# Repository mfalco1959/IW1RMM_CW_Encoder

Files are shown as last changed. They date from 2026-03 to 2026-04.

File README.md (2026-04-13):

# IW1RMM CW Encoder
Live demo:  
https://mfalco1959.github.io/IW1RMM_CW_Encoder/
**Firmware v7.1.5 — IW1RMM (Mauri)**

Morse code keyer WinKey WK3-compliant per ESP32-2432S028R (CYD), con display ILI9341 320×240 touchscreen.
Basato sul firmware originale di VK2IDL, esteso e adattato per il CYD.

---

## Hardware

### Schema elettrico

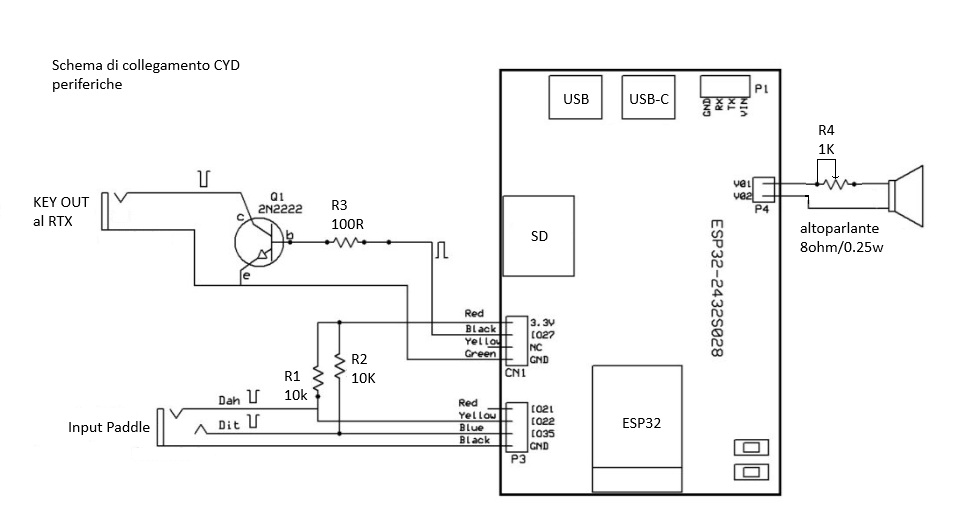
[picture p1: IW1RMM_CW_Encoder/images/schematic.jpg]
Schema elettrico del CW Keyer


### Collegamento paddle e tasto verticale

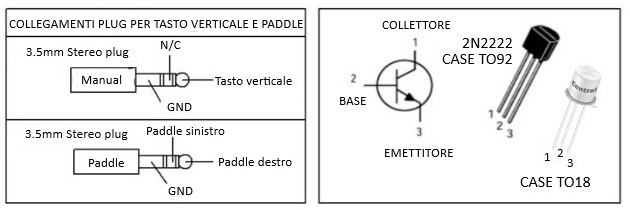
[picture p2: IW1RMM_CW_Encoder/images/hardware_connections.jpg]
Collegamento plug tasto verticale e paddle — transistor 2N2222 TO-92 e TO-18


### Vista interna dei collegamenti

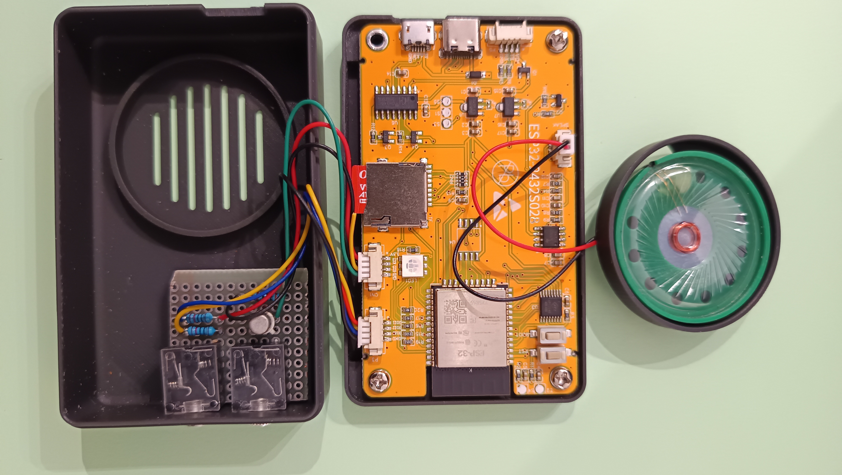
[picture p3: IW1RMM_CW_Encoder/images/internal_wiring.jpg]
Vista interna dei collegamenti


### Vista d'insieme

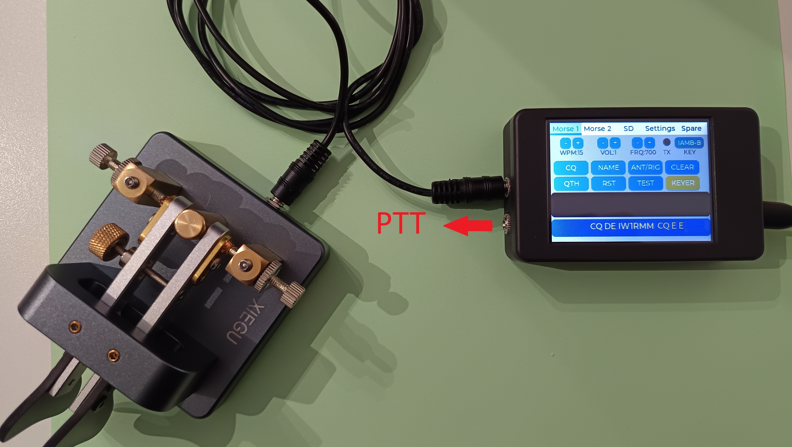
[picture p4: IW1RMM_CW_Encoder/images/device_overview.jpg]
Il CYD nel case con il paddle collegato


---

## Funzionalità

- WinKey WK3 via USB Serial (1200 baud)
- K3NG ASCII command set via Serial e BLE Nordic UART
- LVGL touchscreen UI (5 tab)
- Modalità keyer: Iambic A/B, Bug, Auto, Ultimatic
- SD card playback con logging CSV
- QRSS / HSCW / Beacon / Contest
- Calibrazione touch interattiva a 4 punti
- Orologio con offset GMT, supporto DS3231 RTC
- Farnsworth, Prosign, DAH ratio, Spacing weight
- Memorie K3NG A–Z (NVS)
- Messaggi preimpostati (6 slot, NVS)

---

## Interfaccia — Screenshots

### Tab Morse 1

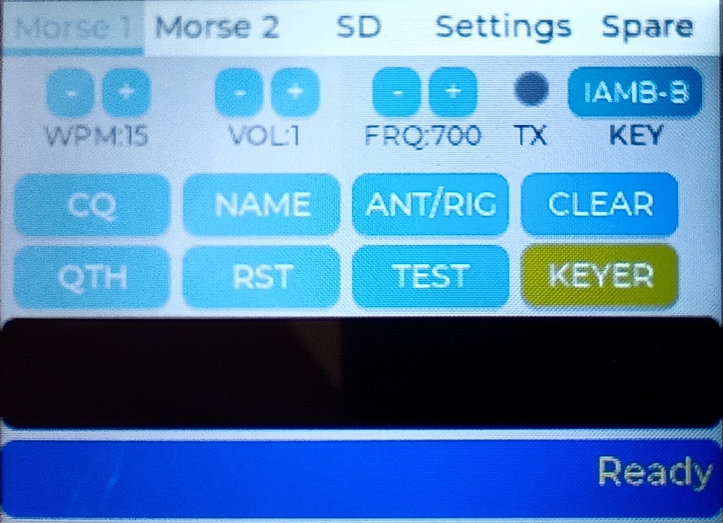
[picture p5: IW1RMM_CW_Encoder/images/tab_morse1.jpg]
Schermata Tab Morse 1


### Keyboard — long press

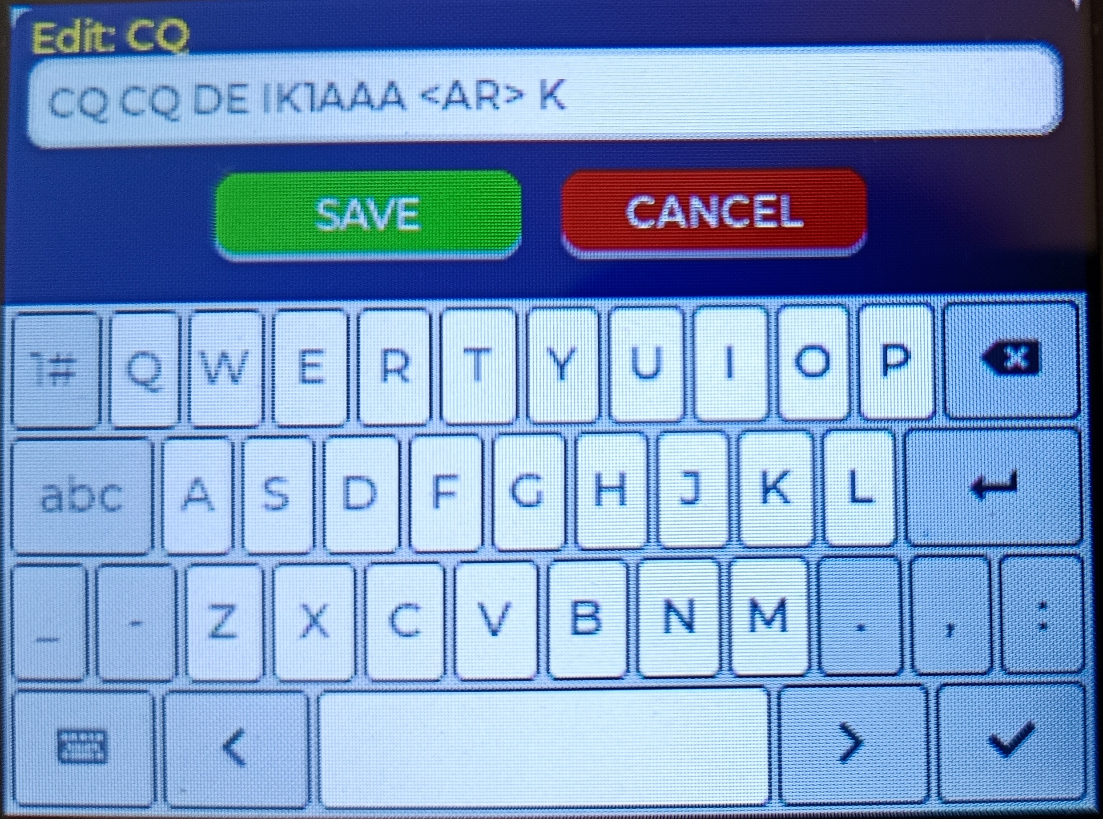
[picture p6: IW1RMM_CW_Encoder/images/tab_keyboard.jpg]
Schermata Keyboard — long press sui tasti CQ, NAME ecc.


### Tab Morse 2

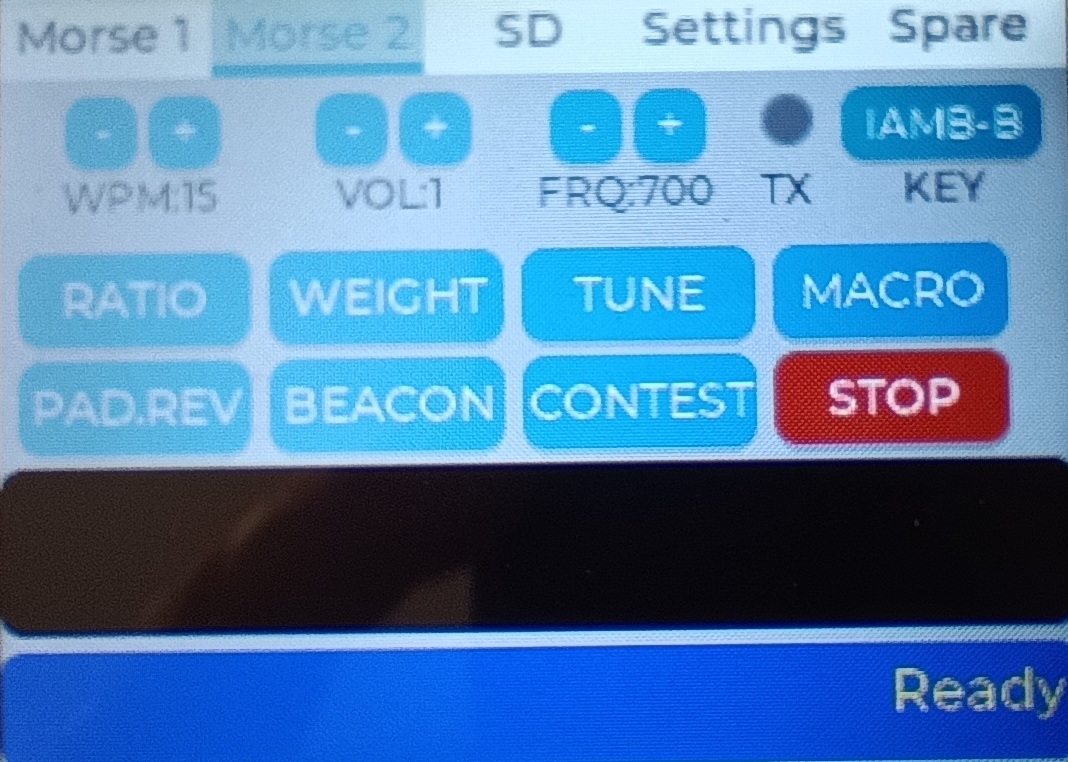
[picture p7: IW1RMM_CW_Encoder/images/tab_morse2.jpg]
Schermata Tab Morse 2


### Tab SD

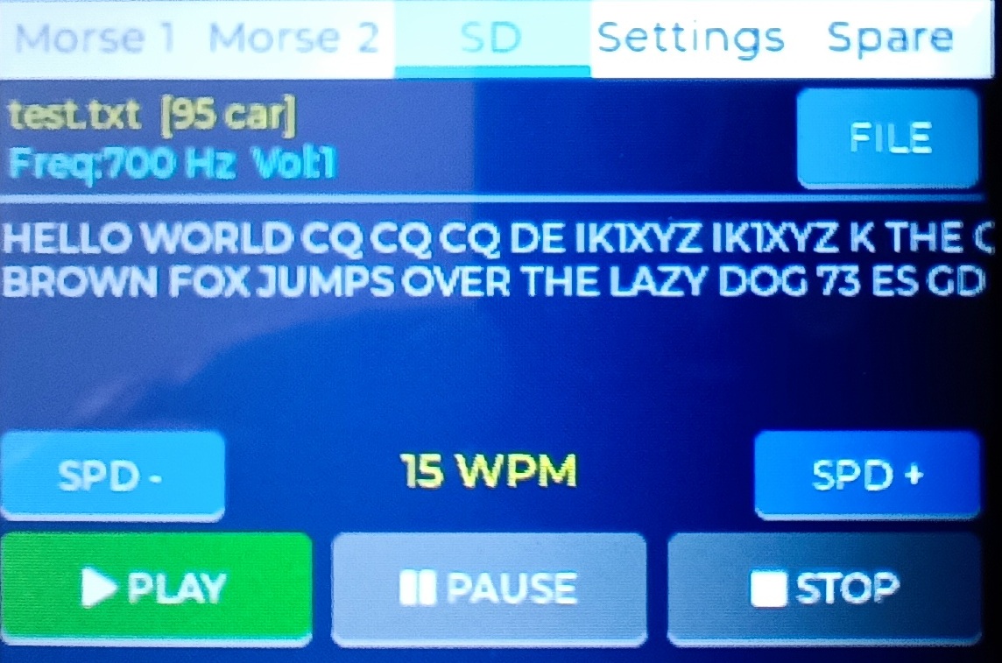
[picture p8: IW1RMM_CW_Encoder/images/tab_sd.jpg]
Schermata Tab SD


### Tab Settings — stato di default

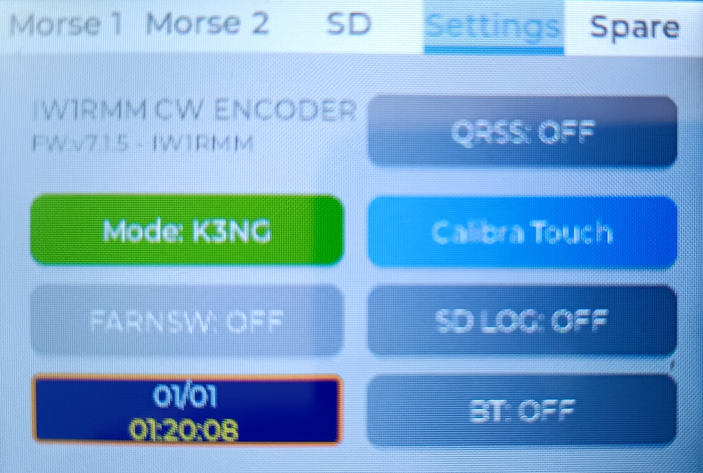
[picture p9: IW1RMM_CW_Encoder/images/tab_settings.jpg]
Schermata Tab Settings — stato di default


### Tab Settings — con i tasti attivi

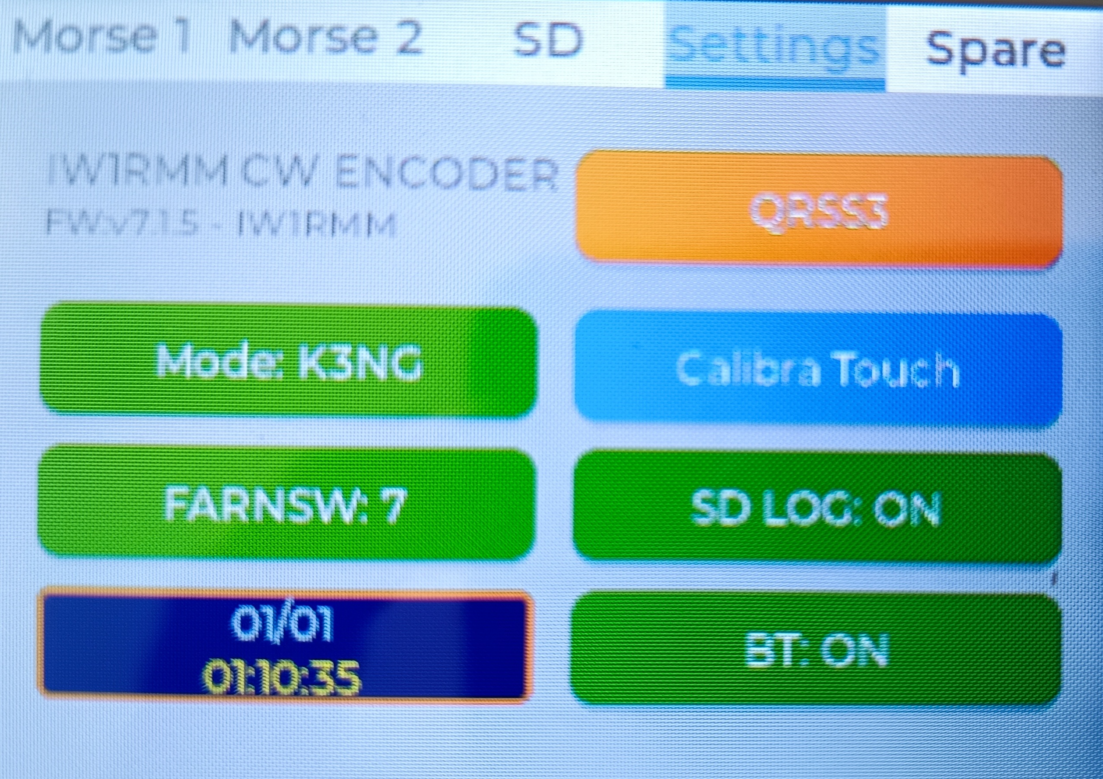
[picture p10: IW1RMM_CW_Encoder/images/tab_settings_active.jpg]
Schermata Tab Settings — con i tasti attivi


---

## BLE

Il firmware espone un servizio Nordic UART (NUS) con nome **VK2IDL_Morse**.  
Supporta lo stesso set di comandi K3NG disponibile via Serial.

### Comandi K3NG via BLE — screenshot smartphone

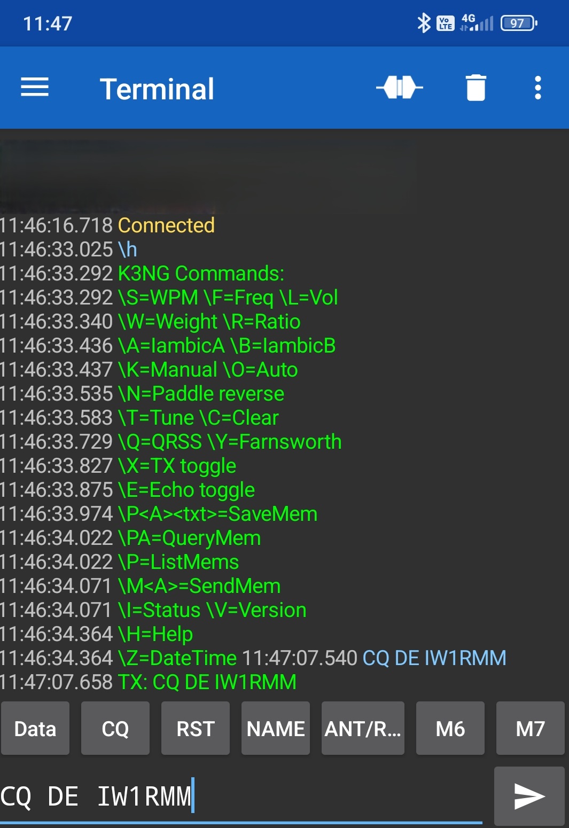
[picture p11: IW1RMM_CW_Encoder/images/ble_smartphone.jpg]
Screenshot smartphone — comandi K3NG via BLE


---

## Pinout ESP32-2432S028R (CYD)

| GPIO | Funzione | Note |
|---|---|---|
| 27 | KEY / PTT output | Uscita keyer |
| 26 | Sidetone DAC | Audio 300–1200 Hz |
| 22 | DIT input | Paddle |
| 21 | DAH input | Paddle |
| 5 | SD_CS | SPI SD card |
| 23 | SD_MOSI | SPI SD card |
| 19 | SD_MISO | SPI SD card |
| 18 | SD_SCK | SPI SD card |
| 2 | TFT_RS | Display ILI9341 |
| 15 | TFT_CS | Display ILI9341 |
| 4 | XPT2046 CS | Touch |
| 36 | XPT2046 IRQ | Touch interrupt |

---

## Dipendenze (librerie Arduino)

| Libreria | Versione | Autore |
|---|---|---|
| lvgl | **8.4.0** | LVGL |
| TFT_eSPI | **2.5.43** | Bodmer |
| XPT2046_Touchscreen | **1.4** | Paul Stoffregen |
| DacESP32 | **2.1.2** | Thomas Jentzsch |
| Preferences (NVS) | built-in | Espressif |
| BLE (BLEDevice/BLEServer/BLEUtils/BLE2902) | built-in | Espressif |

> ⚠️ Testato con ESP32 Arduino Core **3.x**. Le librerie BLE e DacESP32 richiedono Core 3.x — non usare la versione 2.x.

---

## Installazione

1. Clona il repository
```bash
git clone https://github.com/TUO_USER/IW1RMM_CW_Encoder.git
```
2. Copia `include/lv_conf.h` nella cartella dello sketch (stessa directory di `IW1RMM_CW_Encoder.ino`)
3. Configura `User_Setup.h` di TFT_eSPI (vedi `docs/User_Setup_example.h`)
4. Compila con Arduino IDE — board: **ESP32 Dev Module**  
   In **Tools**, imposta:
   - Flash Mode: **DIO**
   - Flash Frequency: **40MHz**
   - Partition Scheme: **Huge APP (3MB No OTA/1MB SPIFFS)**
   - Upload Speed: **115200**
5. Upload via Arduino IDE — il firmware è di grandi dimensioni, **l'upload richiederà alcuni minuti**.

> ⚠️ **DIO + 40MHz sono obbligatori.** Le schede CYD usano spesso il chip flash ZBIT ZB25VQ32, sensibile a impostazioni QIO o 80MHz — l'uso di QIO o 80MHz può causare errori di upload o boot loop.

> 💡 **Velocità di upload:** 115200 baud è il valore sicuro e raccomandato. Se si prevede di fare pochi upload è possibile provare a incrementare la velocità (es. 460800 o 921600) per ridurre i tempi, ma la stabilità dipende dal cavo USB e dal driver del PC.

---

## Comandi K3NG principali

| Comando | Funzione |
|---|---|
| `\Snn` | Imposta velocità (WPM) |
| `\Fnnnn` | Imposta frequenza sidetone (Hz) |
| `\Ln` | Imposta livello volume (0–4) |
| `\R nnn` | DAH ratio × 100 (es. \R300 = 3.0) |
| `\W nnn` | Spacing weight × 100 (es. \W100 = 1.0) |
| `\Y nn` | Farnsworth WPM (0 = disabilita) |
| `\Q n` | QRSS (0/3/6/10/30 secondi per dit) |
| `\T` | TUNE — portante continua |
| `\J` | Reset calibrazione touch |
| `\Z DDMMAAAAHHmmSS` | Imposta orologio |
| `\G ±n` | Offset GMT |
| `\PA testo` | Salva memoria K3NG (A–Z) |
| `\MA` | Invia memoria K3NG A |
| `\P` | Lista tutte le memorie |
| `\?` | Help completo |

---

## Versione

| Versione | Data | Note |
|---|---|---|
| v7.1.4 | 2026-03 | Touch calibration, prosign, DS3231, K3NG esteso |

---

## Crediti

- Firmware originale: **VK2IDL**
- Modifiche, estensioni e adattamento CYD: **IW1RMM (Mauri)**, 2025–2026

---

## Licenza

GPL v3 — vedi file `LICENSE`

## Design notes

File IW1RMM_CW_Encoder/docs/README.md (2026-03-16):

# IW1RMM CW Encoder

**A complete Morse code keyer for the ESP32 CYD — firmware v7.1.4**





**Developed by Mauri IW1RMM, 2025–2026 — Based on original firmware by VK2IDL**

---

## Overview

The IW1RMM CW Encoder turns a €10 ESP32 touchscreen board into a full-featured
Morse code keyer. Plug in your paddle and key — everything else is on the touchscreen.

Hardware: **ESP32-2432S028R** (CYD — Cheap Yellow Display), ILI9341 320×240
colour touchscreen, XPT2046 resistive touch, built-in BLE, MicroSD slot.

---

## Features

### Keying & Paddle
- Iambic A, Iambic B, Manual (straight key), Auto (electronic bug), Ultimatic
- Real-time character decoding: every transmitted character appears on the scrolling display
- Paddle swap (DIT/DAH) in one tap

### Touchscreen Interface
- LVGL-based UI — 5 tabs: Morse 1, Morse 2, SD, Settings, Spare
- Interactive 4-point touch calibration on first boot, stored in NVS *(NEW v7.1.4)*
- Scrolling text bars show transmitted text live
- Virtual keyboard for message editing directly on screen

### Speed & Timing
- 5 to 100 WPM, adjustable on screen
- DAH ratio (2.0–4.5×), spacing weight, Farnsworth character spacing
- All values saved to non-volatile memory, restored on every boot

### Preset Messages
- 6 editable message slots: CQ, Name, Test, Ant/Rig, RST, Free
- Send with one tap, edit via on-screen keyboard, stored permanently in NVS
- Messages can be sent individually or chained

### SD Card Player
- Load any `.txt` file from MicroSD and transmit in Morse
- PLAY / PAUSE / STOP — text scrolls live on display during transmission
- Session logging to CSV with timestamp, WPM, frequency

### Audio
- Internal ESP32 DAC sidetone — 300 to 1200 Hz, 4 volume levels
- No external audio hardware required

### Wireless BLE Control
- Nordic UART BLE service — control from any Android phone or PC *(FIX v7.1.3)*
- K3NG ASCII command set over BLE: set speed, play memories, query status
- Always available regardless of operating mode

### Beacon & Contest
- Beacon: automatic CQ at configurable intervals (10–600 s)
- Contest: auto-incrementing serial number, saved to NVS

### Special Modes
- HSCW (60–100+ WPM) for meteor scatter and aurora
- QRSS (3s, 6s, 10s, 30s per DIT) for low-power propagation experiments
- Full prosign support: `<AR>` `<SK>` `<BT>` `<KN>` `<AS>` `<SN>`
- Built-in clock — optional DS3231 RTC for persistent timekeeping

### PC Integration (optional)
- **WinKey 2.3** binary protocol at 1200 baud — for N1MM+, Win-Test, DXLog, Logger32
- **K3NG serial** ASCII commands at 115200 baud via USB

### Architecture
- FreeRTOS: morseTask on Core 0, LVGL on Core 1
- 1 kHz hardware timer for sub-millisecond keying accuracy
- Non-blocking design throughout — no `delay()` in timing-critical paths

---

## Hardware

| Component | Detail |
|---|---|
| Board | ESP32-2432S028R (CYD) |
| MCU | ESP32-D0WD dual-core 240 MHz · 520 KB RAM · 4 MB flash |
| Display | ILI9341 2.8" TFT 320×240 · SPI (VSPI) |
| Touch | XPT2046 resistive · SPI (HSPI) · 4-point calibrated |
| KEY / PTT output | GPIO 27 · shared pin · HIGH = active |
| Sidetone | GPIO 25 DAC · 300–1200 Hz |
| Left paddle (DIT) | GPIO 35 |
| Right paddle (DAH) | GPIO 22 |
| SD card | HSPI · GPIO 18 / 19 / 23 / 5 |
| Power | USB-C 5V · no external supply needed |

---

## Installation

### 1. Install the ESP32 board package

In Arduino IDE: **File → Preferences → Additional boards manager URLs**, add:

```
https://raw.githubusercontent.com/espressif/arduino-esp32/gh-pages/package_esp32_index.json
```

Then **Tools → Board → Boards Manager** → search `esp32` → install **esp32 by Espressif Systems**.

> **Requires ESP32 Arduino Core 3.x** — DacESP32 and BLE libraries require Core 3.x. Do not use 2.x.

### 2. Install required libraries

In Arduino IDE: **Sketch → Include Library → Manage Libraries**

| Library | Author | How to install |
|---|---|---|
| lvgl | LVGL | Library Manager → search `lvgl` |
| TFT_eSPI | Bodmer | Library Manager → search `TFT_eSPI` |
| XPT2046_Touchscreen | Paul Stoffregen | Library Manager → search `XPT2046` |
| DacESP32 | Florian Tünte | Library Manager → search `DacESP32` |
| SD | Arduino | Built-in — no install needed |
| SPI | Arduino | Built-in — no install needed |
| Preferences | Espressif | Built-in with ESP32 Core |
| BLEDevice / BLEServer / BLEUtils / BLE2902 | Espressif | Built-in with ESP32 Core |
| esp_bt.h | Espressif | Built-in with ESP32 Core (ESP-IDF) |

### 3. Configure TFT_eSPI

Copy `docs/User_Setup_example.h` to your TFT_eSPI library folder
(typically `Documents/Arduino/libraries/TFT_eSPI/`) and rename it `User_Setup.h`.

```cpp
#define ILI9341_DRIVER
#define TFT_MISO  12    // ← must be defined, do NOT comment out
#define TFT_MOSI  13
#define TFT_SCLK  14
#define TFT_CS    15
#define TFT_DC     2
#define TFT_RST   -1
#define TOUCH_CS  -1
#define SPI_FREQUENCY  40000000
```

> **Important**: `TFT_MISO 12` must be defined and not commented out — the SD card will fail to initialise otherwise.

### 4. Copy lv_conf.h

Copy `include/lv_conf.h` to your LVGL library folder
(typically `Documents/Arduino/libraries/lvgl/`), replacing the existing file.
This enables the fonts used by the UI — without it the sketch will not compile.

### 5. Arduino IDE upload settings

| Setting | Value |
|---|---|
| Board | ESP32 Dev Module |
| Flash Mode | **DIO** |
| Flash Frequency | **40 MHz** |
| Partition Scheme | Default 4MB with spiffs |
| Upload Speed | 115200 |

> **DIO + 40 MHz are mandatory.** CYD boards often use ZBIT ZB25VQ32 flash chips
> that are sensitive to faster or QIO settings — using QIO or 80 MHz will cause
> upload failures or boot loops.

### 6. Upload

Open `IW1RMM_CW_Encoder/IW1RMM_CW_Encoder.ino` in Arduino IDE, select the correct
COM port under **Tools → Port**, click **Upload**.

On first boot, the **touch calibration wizard** starts automatically — touch each
of the 4 corner crosshairs as instructed. Calibration is saved permanently and
will not repeat on subsequent boots.

### Alternative: esptool

```bash
python -m esptool --chip esp32 --port COM4 --baud 115200 \
  --before default-reset --after hard-reset \
  write-flash -z --flash-mode dio --flash-freq 40m --flash-size detect \
  0x10000 IW1RMM_CW_Encoder_v714.bin
```

Replace `COM4` with your port (Linux: `/dev/ttyUSB0`, Mac: `/dev/cu.usbserial-*`).

---

## K3NG Serial / BLE Commands (selection)

| Command | Function |
|---|---|
| `\S nn` | Set speed (WPM) |
| `\W nn` | Set weight |
| `\F nn` | Set Farnsworth WPM |
| `\Y nn` | Set sidetone frequency (Hz) |
| `\M x text` | Store memory slot A–Z |
| `\P x` | Play memory slot A–Z |
| `\Z hh:mm:ss` | Set clock |
| `\J` | Reset touch calibration |
| `\X` | Toggle HSCW mode |
| `\H` | Help — full command list |
| `\V` | Firmware version |

Full reference: see `docs/` folder.

---

## Version History

| Version | Changes |
|---|---|
| v7.1.4 | Interactive 4-point touch calibration, NVS namespace `touch_cal`, K3NG commands `\J \Y \X \E` |
| v7.1.3 | BLE fix: device name now visible on Android scan |
| v7.1.2 | MANUAL mode fix, prosign display, `mySet[]` extended to 121 elements (full ITU) |
| v7.1.1 | FreeRTOS multi-task refactor, native BLEDevice |
| v6.9.0 | Base version — VK2IDL original firmware, IW1RMM modifications begin |

---

## Credits

- **Original firmware**: VK2IDL — foundational CW encoder design
- **Development & extensions**: Mauri IW1RMM, 2025–2026
- **K3NG keyer**: Anthony Good K3NG — [github.com/k3ng/k3ng_cw_keyer](https://github.com/k3ng/k3ng_cw_keyer)
- **WinKey protocol**: K1EL — [k1el.com](https://www.k1el.com)
- **LVGL**: [lvgl.io](https://lvgl.io)
- **CYD community**: Brian Lough — [ESP32 Cheap Yellow Display](https://github.com/witnessmenow/ESP32-Cheap-Yellow-Display)

---

## License

This project is licensed under the **GNU General Public License v3.0**.
See [LICENSE](LICENSE) for the full text.

---

*73 de IW1RMM — Mauri, Genova, Italy*

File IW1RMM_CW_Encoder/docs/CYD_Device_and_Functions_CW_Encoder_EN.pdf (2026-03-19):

# IW1RMM CW ENCODER

### Technical Documentation

Firmware v7.1.4 — ESP32 CYD | March 2026
IW1RMM (Mauri) — Based on original VK2IDL firmware

### Firmware Version History

Version | Main changes
v6.9.0 | Base version. Complete Morse keyer, BLE Nordic UART, SD player, WinKey 2.3, K3NG serial, LVGL 5 tabs, clock, QRSS, Farnsworth, beacon, contest.
v7.1.1 | FreeRTOS multi-task architecture refactoring. BLE with native BLEDevice (not NimBLE).
v7.1.2 | Fix MANUAL mode: characters now appear on text bars. mySet[] extended from 64 to 121 elements (full ITU punctuation + prosigns). Fix AR index (43→42). Prosigns displayed as readable text: <AR> <BT> <SK> <SN> <AS> <KN>.
v7.1.3 | Fix BLE 'unnamed': device name VK2IDL_Morse now appears correctly on Android during BLE scan.
v7.1.4 | Interactive 4-point touch calibration. Separate NVS namespace 'touch_cal'. Fallback protections, timeout, serial escape. \J command for calibration reset via serial.

### Part I — The Device: ESP32 CYD

### 1.1 What is the CYD?

CYD stands for Cheap Yellow Display, a nickname affectionately coined by the maker community for a Chinese-made electronic board: the ESP32-2432S028R. The name comes from the yellow colour of the PCB (printed circuit board) and the fact that it integrates everything needed for a touchscreen project at a very low cost, generally under 10 euros.
Despite its apparent simplicity, the CYD is a complete and capable platform, based on the ESP32, one of the most widely used microcontrollers in the world for hobbyist and low-cost professional projects.

### 1.2 Integrated Hardware Components

The CYD includes the following components on a single board:
- ESP32 microcontroller — dual-core processor at 240 MHz, with integrated Wi-Fi and Bluetooth, 520 KB RAM, 4 MB flash memory. Runs the firmware and manages all peripherals simultaneously.
- ILI9341 TFT display — 2.8-inch colour screen, 320×240 pixel resolution, LED backlight. Shows the graphical interface of the Morse keyer.
- XPT2046 resistive touchscreen — touch panel overlaid on the display, allows control via finger or stylus. It is resistive (not capacitive like modern smartphones): it works with any rigid object.

- MicroSD card slot — connector for memory cards up to several GB. Used in this project to load text files for Morse transmission and for session logging.
- RGB LED — small tricolour indicator (red, green, blue) controllable via firmware for visual feedback.
- GPIO connectors — a set of input/output pins available for external peripherals: used in this project for the Morse paddle, DAC audio output, PTT and RTC clock.

### 1.3 Why ESP32 and not a classic Arduino?

An Arduino Uno or Nano would have insufficient memory and speed to simultaneously manage: an LVGL graphical GUI, real-time Morse keyer logic, Bluetooth Low Energy, SD card reading, and serial monitoring. The ESP32 has two independent cores: this project uses them in a dedicated manner — Core 0 handles Morse and serial, Core 1 handles the graphical interface — avoiding interference and ensuring precise Morse transmission timing.

### 1.4 The SPI Bus: A Critical Aspect on the CYD

The display, touchscreen and SD card all communicate via the SPI (Serial Peripheral Interface) protocol. On the CYD these three physical buses are separate (each with its own pins) but must be initialised carefully to avoid conflicts. The firmware manages this complexity transparently to the end user. A critical detail: the SD card must be initialised before the display (tft.begin()), because the display reinitialises the SPI buses and can make the SD inaccessible if initialised afterwards.

### 1.5 Power and Connectivity

The CYD is powered via USB-C at 5V, the same connector used to upload firmware. No external power supply is required. For Bluetooth Low Energy (BLE) no additional hardware is needed: it is already integrated in the ESP32. Wi-Fi is not used by the current firmware but is available for future development.

### 1.6 Known Limitations

- The ZBIT flash memory present on some CYD variants is sensitive to programming speed: Flash Mode DIO and 40 MHz frequency must be set to avoid upload errors.
- The resistive screen requires initial calibration: firmware v7.1.4 includes an automatic 4-point guided procedure that runs on first boot on each new device.
- The SD card must be initialised before the display to avoid SPI bus conflicts.
- The lv_conf.h file (LVGL configuration) must be copied into the Arduino IDE LVGL library folder, otherwise fonts will not be found during compilation.

### Part II — CW Encoder Features

The following is a complete list of features provided by the IW1RMM CW Encoder firmware v7.1.4. Features that are new or changed since v6.9.0 are marked with the ● NEW badge.

### 2.1 Keying and Paddle

Iambic A Mode
Standard iambic mode: when both paddle levers are squeezed, the keyer generates alternating DITs and DAHs starting from the most recently pressed element. No element queuing on press. Iambic B Mode
Same as Iambic A but with 'squeeze memory': if both levers are squeezed, a complementary element is added at the end of the last element. This is the firmware default mode.

Manual Mode (Straight Key)

The left paddle (DIT) works as a manual telegraph key: the carrier is activated on press and deactivated on release. Suitable for those using a vertical or straight key.
In v7.1.4 this mode was corrected: transmitted characters are now correctly decoded and displayed on the text bars of the display. Press duration is measured at key release and classified as DIT (duration < 2×ditLength) or DAH (duration ≥ 2×ditLength), exactly as in iambic modes. Auto Mode
Automatic transmission of buffer contents without using the paddle. The keyer transmits queued text at constant speed. Operates as a single-lever (mono-leva) electronic bug: responds only to the active lever, no automatic buffer queuing.

### 2.2 Speed and Timing

WPM (Words Per Minute)
Transmission speed adjustment from 5 to 100 WPM via on-screen +/- buttons. The value is saved to non-volatile memory and restored on reboot.
DAH Ratio
Ratio between DAH and DIT duration. The standard value is 3:1 (DAH lasts three times a DIT). Adjustable via popup with slider from 2.0 to 4.5.
Spacing Weight
Corrects inter-element space timing. A value above 1.0 increases spaces, a value below reduces them. Useful for adapting rhythm to personal technique.
Farnsworth Timing
Learning technique: individual characters are transmitted at the nominal WPM speed, but spaces between characters are extended to facilitate decoding. Activatable from Settings with a slider for the effective spacing WPM.

### 2.3 Audio

Tone Frequency
Sidetone frequency generated by the ESP32 internal DAC (GPIO 26), adjustable from 300 to 1200 Hz via on-screen +/- buttons. Value saved to NVS.
Volume
Four DAC signal attenuation levels (0=mute, 4=maximum), controllable from screen. Level 0 completely mutes the sidetone.

### 2.4 Preset Messages

Six configurable message slots accessible via touchscreen buttons: CQ, Name, Test, Ant/Rig, RST, Free. Each can be edited via on-screen keyboard and saved permanently to NVS. Messages can be transmitted individually or concatenated. A space is automatically added between consecutive messages.

### 2.5 K3NG Serial Commands

The firmware supports the K3NG Arduino Keyer protocol via USB serial at 115200 baud and via BLE. Commands start with the backslash character (\). Main commands:
- \S nn — Set speed in WPM
- \W nn — Set weight

- \F nn — Set Farnsworth WPM
- \M x text — Store memory (A–Z)
- \P x — Play memory (A–Z)
- \H — Help / command list
- \V — Firmware version
- \Z hh:mm:ss — Set clock
- \J — Reset touch calibration (NEW v7.1.4)
- \Y — Set sidetone frequency (NEW v7.1.4)
- \X — Toggle HSCW mode (NEW v7.1.4)
- \E — Toggle extended display (NEW v7.1.4)

### 2.6 Beacon Mode

Automatically transmits a configurable message at regular intervals (1 to 99 seconds). Useful for unattended beacon operation.

### 2.7 Contest Mode

Adds a progressive numeric counter to transmission for CW competitions. The number is automatically incremented after each transmission and saved to NVS.

### 2.8 TUNE

Transmits a continuous carrier for amplifier or antenna tuning. Also activates the PTT output (pin 27, HIGH=ON). Deactivated by pressing the button again.

### 2.9 Paddle Swap

Swaps the DIT and DAH functions between the two paddle levers. Useful for left-handed operators or paddles with reversed polarity.

### 2.10 QRSS Mode

Transmission at extremely reduced speed (3 to 30 seconds per DIT) for low-power propagation experiments, receivable with SDR software and special decoders (e.g. QRSS VD, Argo). Four steps: 3s, 6s, 10s, 30s per DIT.

### 2.11 SD Card Playback

The SD tab allows text files to be selected from the MicroSD card and transmitted in Morse at configurable speed and volume. Available functions: PLAY, PAUSE, STOP. The first lines of text being transmitted are displayed in real time. Text also scrolls on the blue and black bars of the Morse 1 and Morse 2 tabs.

### 2.12 SD Logging

Records all transmitted characters to a CSV file on the SD card, with timestamp and session metadata (WPM, frequency, uptime). Activatable from Settings.

### 2.13 Bluetooth Low Energy (BLE)

Implements a BLE UART service (Nordic NUS) that allows controlling the keyer from a smartphone or computer via Bluetooth. Commands follow the K3NG or WinKey protocol depending on the active mode. Connection status is visible in the Settings tab.

With v7.1.3 the 'unnamed' issue was resolved: the name VK2IDL_Morse is now explicitly set in the primary advertising payload, so Android displays it correctly during BLE scan without requiring active scanning.

### 2.14 WinKey 2.x Protocol

Compatibility with the WinKey 2.3 protocol (K1EL), widely supported by major logging and contest software (N1MM+, DXLog, Logger32, WKdemo, etc.). When enabled, the CYD appears as a WinKey hardware keyer via USB serial port. Handles host open/close, speed commands, PTT lead/tail, mode register. WinKey mode operates at 1200 baud.

### 2.15 K3NG Protocol (Serial)

As an alternative to WinKey, the firmware supports the K3NG Arduino Keyer protocol via USB serial at 115200 baud. Allows control from software and text input from a terminal. Special commands start with the backslash character (\).

### 2.16 Integrated Clock

The firmware includes a digital clock displayed on screen. The clock label border is green when the time is set (year > 1970), red otherwise. Time can be set via serial command \Z. If the DS3231 hardware module is connected to pins SDA=16, SCL=17, the time is loaded automatically at boot and persists between reboots.

### 2.17 Touch Calibration

With v7.1.4, touch panel calibration has become fully interactive and safe. On first boot on a new device, or after pressing 'Calibrate Touch' in Settings, a guided 4-point procedure starts automatically:
- The screen shows a crosshair in each of the 4 corners (top-left, top-right, bottom-right, bottom-left) with on-screen instructions.
- The user touches the centre of each crosshair. The firmware acquires the raw coordinates from the XPT2046 controller.
- At the end, the 4 calibration values are calculated and displayed. If they are within a reasonable range, confirmation is requested (touch or 10-second timeout = automatic confirmation).
- Values are saved to a dedicated NVS namespace ('touch_cal'), separate from operating parameters (WPM, messages, etc.) to avoid accidental deletion.
- If values are out of range or the procedure is cancelled, the sketch automatically uses hardcoded default values — the device always remains functional.
Implemented protections:
- Serial escape: sending 'R' from Serial Monitor during the procedure cancels calibration without blocking the device.
- Range validation: x_min must be between 100 and 1000, x_max between 3000 and 4095, with a minimum excursion of 2000 points. Out-of-range values are automatically discarded.
- \J command (K3NG serial): resets calibration and restarts the guided procedure, works even if touch is completely uncalibrated.
- Rollback safety: versions prior to v7.1.4 ignore the 'touch_cal' namespace and always use hardcoded values — rolling back is always safe.

### 2.18 Real-Time Paddle Decoding

Characters transmitted via paddle are decoded by the firmware and displayed on the scrolling text bars on the display. Decoding uses a Morse binary tree (mySet[] table, 121 elements). From v7.1.2 it also works correctly in Manual mode.

### 2.19 Tab Interface

The graphical interface is organised into 5 tabs: Morse 1 (preset messages and controls), Morse 2 (optimised duplicate), SD (player), Settings (advanced configuration), Spare (features under development — intended to become the CW Trainer tab).

### Part III — Future Development

### 3.1 CW Trainer Tab (Planned)

The Spare tab is intended to become a full CW trainer. Planned features in priority order:
- Echo Trainer (priority 1): the keyer transmits a character/word, the operator repeats it on the paddle, the firmware compares and shows OK/ERROR on the display. The most effective function for those who already have a paddle.
- Koch Trainer — receive (priority 2): current lesson selection via slider, transmission of random groups with only the characters learned up to that lesson, at Farnsworth speed.
- Sending Trainer (priority 3): the display shows a character or word, the operator must send it on the paddle, green/red visual feedback.
- Configurable CW Generator (priority 4): random letters, numbers, callsigns, Q-codes, common words, 5-digit groups.
- Session statistics (priority 5): accuracy %, effective WPM, counters. Saveable to SD.

### 3.2 Documentation Ideas

- Block diagram of the data flow between FreeRTOS tasks (morseTask, serialTask, LVGL loop).
- Complete table of CYD pins used by the project, with functional description.
- Operator guide: how to use the keyer from scratch, step by step.
- Quick Reference Card (1 page) printable to keep next to the radio.
- Table of WinKey 2.3 commands: supported vs not supported.
- FAQ: most common issues (SD not found, touch not calibrated, BLE not connecting).

### 3.3 Firmware Ideas

- Wi-Fi NTP: automatic clock synchronisation via Wi-Fi on boot.
- WebSerial: web interface to configure the keyer without a physical serial connection.
- Full K3NG memories (A-Z): 26 messages programmable from serial.
- SD log export in ADIF format for direct import into amateur radio logs.
- OTA update: firmware update via Wi-Fi without a connected computer.

Document by IW1RMM (Mauri) — IW1RMM CW Encoder — Based on VK2IDL firmware — v7.1.4 — March 2026

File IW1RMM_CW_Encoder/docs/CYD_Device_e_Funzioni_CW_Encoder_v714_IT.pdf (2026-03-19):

# VK2IDL CW ENCODER — Documentazione Tecnica

Versione firmware 7.1.4 — ESP32 CYD | Marzo 2026
Documento aggiornato dalla v6.9.0 alla v7.1.4 — IW1RMM (Mauri)

## Storico versioni firmware

Versione | Modifiche principali
v6.9.0 | Versione base. Keyer morse completo, BLE Nordic UART, SD player, Winkey 2.3, K3NG seriale, LVGL 5 tab, orologio, QRSS, Farnsworth, beacon, contest.
v7.1.1 | Refactoring architettura multi-task FreeRTOS. BLE con BLEDevice nativo (non NimBLE).
v7.1.2 | Fix modalità MANUAL: i caratteri ora appaiono sulle barre di testo. mySet[] esteso da 64 a 121 elementi (punteggiatura ITU completa + prosign). Fix indice AR (43→42). Prosign visualizzati come testo leggibile: <AR> <BT> <SK> <SN> <AS> <KN>.
v7.1.3 | Fix BLE 'unnamed': il nome VK2IDL_Morse ora appare correttamente su Android durante la scansione BLE.
v7.1.4 | Calibrazione touch interattiva a 4 punti. Namespace NVS separato 'touch_cal'. Protezioni fallback, timeout, escape seriale. Comando \J per reset calibrazione via seriale.

## Parte I — Il dispositivo: ESP32 CYD

### 1.1 Che cos'è il CYD?

CYD è l'abbreviazione di Cheap Yellow Display, un nome scherzoso e affettuoso con cui la comunità dei maker ha battezzato una scheda elettronica di produzione cinese: la ESP32-2432S028R. La denominazione nasce dal colore giallo del PCB (la piastra a circuiti stampati) e dal fatto che integra tutto il necessario per un progetto touchscreen a un prezzo molto contenuto, generalmente inferiore ai 10 euro.

Nonostante la semplicità apparente, il CYD è una piattaforma completa e performante, basata sull'ESP32, uno dei microcontrollori più diffusi al mondo nell'ambito dei progetti hobbistici e professionali di fascia bassa.

### 1.2 Componenti hardware integrati

Il CYD racchiude sulla stessa scheda i seguenti elementi:

- Microcontrollore ESP32 — processore dual-core a 240 MHz, con Wi-Fi e Bluetooth integrati, 520 KB di RAM, 4 MB di memoria flash. Esegue il firmware e gestisce tutte le periferiche simultaneamente.
- Display TFT ILI9341 — schermo a colori da 2,8 pollici, risoluzione 320×240 pixel, retroilluminazione LED. Visualizza l'interfaccia grafica del keyer morse.
- Touch screen resistivo XPT2046 — pannello tattile sovrapposto al display, consente il controllo dell'apparecchio tramite tocco con il dito o uno stilo. Non è capacitivo (come i moderni smartphone) ma resistivo: funziona con qualsiasi oggetto rigido.
- Slot per scheda MicroSD — connettore per schede di memoria fino a diversi GB. Nel progetto viene usato per caricare file di testo da trasmettere in morse e per il logging delle sessioni.
- LED RGB — piccolo indicatore luminoso tricolore (rosso, verde, blu) gestibile via firmware per segnalazioni visive.
- Connettori GPIO — una serie di pin di input/output disponibili per collegare periferiche esterne: nel progetto vengono usati per il paddle morse, l'uscita audio DAC, il PTT e il clock RTC.

### 1.3 Perché l'ESP32 e non un Arduino classico?

Un Arduino Uno o Nano avrebbe memoria e velocità insufficienti per gestire simultaneamente: una GUI grafica LVGL, la logica del keyer morse in tempo reale, il Bluetooth Low Energy, la lettura della scheda SD e il serial monitoring. L'ESP32 dispone di due core indipendenti: il progetto li usa in modo dedicato — il Core 0 gestisce il morse e il seriale, il Core 1 gestisce l'interfaccia grafica — evitando interferenze e garantendo la precisione dei tempi di trasmissione morse.

### 1.4 Il bus SPI: un aspetto critico sul CYD

Il display, il touch screen e la scheda SD comunicano tutti tramite il protocollo SPI (Serial Peripheral Interface). Sul CYD questi tre bus fisici sono separati (ognuno ha i propri pin) ma devono essere inizializzati con attenzione per evitare conflitti. Il firmware gestisce questa complessità nascondendola all'utente finale. Un dettaglio critico: la scheda SD deve essere inizializzata prima del display (tft.begin()), perché quest'ultimo reinizializza i bus SPI e può rendere inaccessibile la SD se inizializzata prima.

### 1.5 Alimentazione e connettività

Il CYD si alimenta tramite porta USB-C a 5V, lo stesso connettore usato per programmare il firmware. Non richiede alimentazione esterna. Per il Bluetooth Low Energy (BLE) non serve alcun hardware aggiuntivo: è già integrato nell'ESP32. La connessione Wi-Fi non è utilizzata dal firmware attuale ma è disponibile per sviluppi futuri.

### 1.6 Limitazioni note

- La memoria flash ZBIT presente su alcune varianti CYD è sensibile alla velocità di programmazione: occorre impostare Flash Mode DIO e frequenza 40 MHz per evitare errori di upload.
- Lo schermo resistivo richiede una calibrazione iniziale: il firmware v7.1.4 include una procedura guidata a 4 punti che si avvia automaticamente al primo avvio su ogni nuovo device.
- La SD card deve essere inizializzata prima del display per evitare conflitti sul bus SPI.

- Il file lv_conf.h (configurazione LVGL) deve essere copiato nella cartella della libreria LVGL di Arduino IDE, altrimenti i font non vengono trovati in compilazione.

## Parte II — Funzioni del CW Encoder

Di seguito è riportato l'elenco completo delle funzionalità offerte dal firmware VK2IDL CW Encoder v7.1.4. Le funzionalità nuove o modificate rispetto alla v6.9.0 sono segnalate con il badge ● NOVITÀ.

### 2.1 Keying e paddle

Modalità Iambic A
Modalità iambica standard: quando entrambe le levette del paddle sono premute, il keyer genera alternanza di DIT e DAH partendo dall'elemento più recentemente premuto. Non memorizza elementi in coda alla pressione.

Modalità Iambic B
Come Iambic A ma con 'squeeze memory': se si preme entrambe le levette, al termine dell'ultimo elemento viene aggiunto un elemento complementare. Modalità predefinita del firmware.

Modalità Manual (Straight Key) ● NOVITÀ v7.1.2
Il paddle sinistro (DIT) funziona come un tasto telegrafico manuale: la portante viene attivata alla pressione e disattivata al rilascio. Adatto per chi usa un tasto verticale o liscio.
In v7.1.4 questa modalità è stata corretta: i caratteri trasmessi vengono ora correttamente decodificati e visualizzati sulle barre di testo del display. La durata della pressione viene misurata al rilascio del tasto e classificata come DIT (durata < 2×ditLength) o DAH (durata ≥ 2×ditLength), esattamente come nelle modalità iambiche.

Modalità Auto
Invio automatico del contenuto del buffer senza uso del paddle. Il keyer trasmette il testo accodato a velocità costante.

### 2.2 Velocità e timing

WPM (parole al minuto)
Regolazione della velocità di trasmissione da 5 a 100 WPM tramite i pulsanti +/- a schermo. Il valore viene salvato in memoria non volatile e ripristinato al riavvio.

DAH Ratio
Rapporto tra la durata del DAH e del DIT. Il valore standard è 3:1 (il DAH dura tre volte un DIT). Modificabile tramite popup con slider da 2.0 a 4.5.

Spacing Weight
Corregge i tempi di spazio inter-elemento. Un valore superiore a 1.0 aumenta gli spazi, un valore inferiore li riduce. Utile per adattare il ritmo alla propria tecnica.

Farnsworth Timing
Tecnica di apprendimento: i singoli caratteri vengono trasmessi alla velocità nominale WPM impostata, ma gli spazi tra carattere e carattere sono allungati per facilitare la decodifica. Attivabile da Settings con slider per il WPM effettivo di spaziatura.

### 2.3 Audio

Frequenza del tono
Frequenza del sidetone generato dal DAC interno ESP32 (pin GPIO 26), regolabile da 300 a 1200 Hz tramite pulsanti +/- a schermo. Valore salvato in NVS.

Volume
Quattro livelli di attenuazione del segnale DAC (0=muto, 4=massimo), controllabili da schermo. Il livello 0 muta completamente il sidetone.

### 2.4 Messaggi preimpostati

Sei messaggi personalizzabili, accessibili con un tocco sul display:

- CQ — messaggio di chiamata generale (es. CQ CQ DE IW1RMM K)
- NAME — presentazione del nominativo
- ANT/RIG — informazioni sulla stazione
- QTH — posizione geografica
- RST — rapporto di ricezione
- TEST — messaggio di prova

Ogni messaggio può essere modificato tramite long-press sul pulsante: si apre una tastiera virtuale a schermo. Le modifiche vengono salvate in modo permanente nella NVS dell'ESP32 con flush garantito (end/begin/putString/end).

Buffer di testo
I messaggi vengono accodati in un buffer testuale. Il keyer trasmette il testo in modo asincrono: si può accodare il successivo messaggio mentre il precedente è ancora in trasmissione.

Macro
Un settimo pulsante MACRO consente di accodare un testo libero definito dall'utente.

### 2.5 Prosign e punteggiatura

### 2.5 Prosign e punteggiatura ITU ● NOVITÀ v7.1.2

Il firmware riconosce e trasmette correttamente tutti i prosign telegrafici standard ITU-R M.1677. Sul display vengono visualizzati in forma leggibile anziché come caratteri criptici:

Prosign | Display | Sequenza Morse
AR (end of message) | <AR> | . - . - .
BT (paragraph break) | <BT> | - . . . -
SK (end of work) | <SK> | . . . - . -
SN (understood) | <SN> | . . . - .
AS (wait) | <AS> | . - . . .
KN (over only you) | <KN> | - . - - .

Sono supportati anche tutti i simboli di punteggiatura ITU: punto (.-.-.-), virgola (--..--), punto interrogativo (..--...), barra obliqua (-..-.), parentesi, due punti, punto e virgola, esclamativo, trattino, chiocciola (@) e apostrofo.

### 2.6 Modalità Beacon

Il messaggio CQ viene trasmesso automaticamente a intervalli regolari (configurabile da 10 a 600 secondi). Utile per test di propagazione o per beacon non presidiati.

### 2.7 Modalità Contest

Aggiunge alla trasmissione un contatore progressivo numerico per le competizioni CW. Il numero viene incrementato automaticamente dopo ogni trasmissione e salvato in NVS.

### 2.8 TUNE

Trasmette portante continua per la taratura dell'amplificatore o dell'antenna. Attiva anche l'uscita PTT (pin 27, HIGH=ON). Si disattiva premendo nuovamente il pulsante.

### 2.9 Inversione paddle

Scambia le funzioni di DIT e DAH tra le due levette del paddle. Utile per mancini o per paddle con polarità invertita.

### 2.10 Modalità QRSS

Trasmissione a velocità estremamente ridotta (da 3 a 30 secondi per DIT) per esperimenti di propagazione a bassissima potenza, ricevibili con software SDR e decoder speciali (es. QRSS VD, Argo). Quattro step: 3s, 6s, 10s, 30s per DIT.

### 2.11 Riproduzione da scheda SD

Il tab SD consente di selezionare file di testo dalla scheda MicroSD e trasmetterli in morse a velocità e volume configurabili. Funzioni disponibili: PLAY, PAUSE, STOP. Vengono visualizzate in tempo reale le prime righe del testo in trasmissione. Il testo scorre anche sulle barre blu e nere dei tab Morse 1 e Morse 2.

### 2.12 Logging su SD

Registra su file CSV nella scheda SD tutti i caratteri trasmessi, con timestamp e metadati di sessione (WPM, frequenza, uptime). Attivabile da Settings.

### 2.13 Bluetooth Low Energy (BLE)

### 2.13 Bluetooth Low Energy (BLE) ● NOVITÀ v7.1.3

Implementa un servizio BLE UART (Nordic NUS) che consente di controllare il keyer da smartphone o computer via Bluetooth. I comandi seguono il protocollo K3NG o Winkey a seconda della modalità attiva. Lo stato di connessione è visibile nel tab Settings.
Con la v7.1.3 è stato risolto il problema 'unnamed': il nome VK2IDL_Morse viene ora impostato esplicitamente nel payload advertising primario, così Android lo mostra correttamente durante la scansione BLE senza necessità di scansione attiva.

### 2.14 Protocollo Winkey 2.x

Compatibilità con il protocollo Winkey 2.3 (K1EL) ampiamente supportato dai principali software di log e contest (N1MM+, DXLog, Logger32, WKdemo, ecc.). Quando abilitato, il CYD appare come un keyer Winkey hardware via porta seriale USB. Gestisce apertura/chiusura host, comandi di velocità, PTT lead/tail, mode register. La modalità Winkey opera a 1200 baud.

### 2.15 Protocollo K3NG (seriale)

In alternativa a Winkey, il firmware supporta il protocollo K3NG Arduino Keyer via seriale USB a 115200 baud. Consente il controllo da software e l'invio di testo da terminale. I comandi speciali iniziano con il carattere backslash (\).

### 2.16 Orologio integrato

Il firmware include un orologio digitale visualizzato a schermo. Il bordo della label orologio è verde quando l'ora è impostata (anno > 1970), rosso altrimenti. L'ora può essere impostata tramite comando seriale \Z. Se è presente il modulo hardware DS3231 collegato ai pin SDA=16, SCL=17, l'ora viene caricata automaticamente al boot e persiste tra i riavvii.

### 2.17 Calibrazione touch

### 2.17 Calibrazione touch ● NOVITÀ v7.1.4

Con la v7.1.4 la calibrazione del pannello touch è diventata completamente interattiva e sicura. Al primo avvio su un nuovo device, o dopo aver premuto 'Calibra Touch' in Settings, si avvia automaticamente una procedura guidata a 4 punti:

- Lo schermo mostra una croce in ciascuno dei 4 angoli (alto-sinistra, alto-destra, basso-destra, basso-sinistra) con istruzioni a video.
- L'utente tocca il centro di ogni croce. Il firmware acquisisce le coordinate raw del controller XPT2046.
- Al termine, vengono calcolati e mostrati i 4 valori di calibrazione. Se sono nel range ragionevole, viene chiesta conferma (tocco o timeout 10 secondi = conferma automatica).
- I valori vengono salvati in un namespace NVS dedicato ('touch_cal'), separato dai parametri operativi (WPM, messaggi, ecc.) per evitare cancellazioni accidentali.
- Se i valori sono fuori range o la procedura viene annullata, lo sketch usa automaticamente i valori hardcoded di default — il device resta sempre funzionante.

Protezioni implementate:
- Escape via seriale: inviare 'R' da Serial Monitor durante la procedura annulla la calibrazione senza bloccare il device.
- Validazione range: x_min deve essere tra 100 e 1000, x_max tra 3000 e 4095, con escursione minima di 2000 punti. Valori fuori range vengono scartati automaticamente.
- Comando \J (K3NG seriale): resetta la calibrazione e riavvia la procedura guidata, funziona anche se il touch è completamente non calibrato.
- Ritorno a versioni precedenti: le versioni precedenti alla v7.1.4 ignorano il namespace 'touch_cal' e usano sempre i valori hardcoded — tornare indietro è sempre sicuro.

### 2.18 Decodifica paddle in tempo reale

I caratteri trasmessi tramite paddle vengono decodificati dal firmware e visualizzati sul display nelle barre di testo scorrevoli. La decodifica avviene tramite albero binario morse (tabella mySet[], 121 elementi). Dalla v7.1.2 funziona correttamente anche in modalità Manual.

### 2.19 Interfaccia a schede (tab)

L'interfaccia grafica è organizzata in 5 schede: Morse 1 (messaggi preimpostati e controlli), Morse 2 (duplicato ottimizzato), SD (player), Settings (configurazione avanzata), Spare (funzioni in sviluppo — destinato a diventare il tab Trainer CW).

## Parte III — Sviluppi futuri

### 3.1 Tab Trainer CW (in pianificazione)

Il tab Spare è destinato a diventare un trainer CW completo. Le funzionalità pianificate in ordine di priorità sono:

- Echo Trainer (priorità 1): il keyer trasmette un carattere/parola, l'operatore lo ripete sul paddle, il firmware confronta e mostra OK/ERRORE sul display. La funzione più efficace per chi ha già il paddle.

- Koch Trainer — ricezione (priorità 2): selezione della lezione corrente tramite slider, trasmissione di gruppi random con i soli caratteri appresi fino a quella lezione, a velocità Farnsworth.
- Sending Trainer (priorità 3): il display mostra un carattere o parola, l'operatore deve inviarlo sul paddle, feedback visivo verde/rosso.
- CW Generator configurabile (priorità 4): lettere random, numeri, callsign, Q-code, parole comuni, gruppi a 5 cifre.
- Statistiche sessione (priorità 5): accuratezza %, WPM effettivi, contatori. Salvabili su SD.

### 3.2 Idee documentazione

- Schema a blocchi del flusso dati tra i task FreeRTOS (morseTask, serialTask, loop LVGL).
- Tabella completa dei pin CYD usati dal progetto, con descrizione funzionale.
- Guida operatore: come usare il keyer da zero, passo per passo.
- Quick Reference Card (1 pagina) stampabile da tenere vicino alla radio.
- Tabella comandi Winkey 2.3 supportati vs non supportati.
- FAQ: problemi più comuni (SD non trovata, touch non calibrato, BLE non si connette).
- Traduzione in inglese per condivisione con la comunità internazionale.

### 3.3 Idee firmware

- Wi-Fi NTP: sincronizzazione automatica dell'orologio via rete Wi-Fi all'avvio.
- WebSerial: interfaccia web per configurare il keyer senza seriale fisico.
- Memorie K3NG complete (A-Z): 26 messaggi programmabili da seriale.
- Export log SD in formato ADIF per importazione diretta nei log radioamatoriali.
- OTA update: aggiornamento firmware via Wi-Fi senza necessità di computer collegato.

Documento redatto da IW1RMM (Mauri) — Progetto VK2IDL CW Encoder — Aggiornato v7.1.4 — Marzo 2026

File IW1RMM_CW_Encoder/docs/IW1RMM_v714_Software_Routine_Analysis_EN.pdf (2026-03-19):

# IW1RMM CW ENCODER

## Firmware v7.1.4 — Software Routine Analysis

### ESP32 CYD | March 2026 — IW1RMM (Mauri)

Based on original VK2IDL firmware

## 1. Firmware Architecture

The firmware is organised into three concurrent FreeRTOS tasks. ESP32 Core 0 runs morseTask (priority 2, stack 8192 bytes) and serialTask (priority 1, stack 4096 bytes). Core 1 runs the Arduino loop() function, which manages LVGL and the graphical interface. Communication between tasks uses a displayQueue (64 messages) and an xMutex for shared variables.

## 2. Initialisation Routines

Routine | Short description | Detail
setup() | Firmware entry point | Starts in sequence: SD card (before display), Serial, mutex/queue, NVS preferences, GPIO pins, LVGL, touch, HW timer, graphical UI, BLE, FreeRTOS tasks. Critical order: SD must be initialised before tft.begin() to avoid SPI bus conflicts.
setupPins() | Configure GPIO | Sets MORSE_OUT (pin 27) as output LOW, PADDLE_DAH (22) with pull-up, PADDLE_DIT (35) as input, initialises ESP32 DAC for sidetone, activates TFT backlight (pin 21).
setupLVGL() | Initialise graphics | Calls lv_init(), initialises ILI9341 display via TFT_eSPI (VSPI), configures LVGL rendering buffer (320×10 pixels), registers display and touch drivers.
setupTouch() | Initialise XPT2046 touch | Initialises dedicated HSPI bus for touch, loads calibration values from NVS namespace 'touch_cal' (if available) or uses hardcoded defaults (x: 220-3730, y: 387-3763), enables horizontal rotation.
setupTimer() | 1 kHz hardware timer | Configures ESP32 hardware timer with 1 ms interrupt. Increments morseTimerTick counter used by morseDelay() for precise timing without blocking the task.
setupTasks() | Create FreeRTOS tasks | Launches morseTask on Core 0 (stack 8192, priority 2) and serialTask on Core 0 (stack 4096, priority 1). LVGL runs in loop() on Core 1.
loadPreferences() | Load NVS parameters | Reads from namespace 'cyd-morse' (NVS flash): WPM, frequency, volume, dahRatio, weight, paddleReversed, beaconInterval, contestCounter, messages msg0..msg5. Applies values and calculates Morse timing.

savePreferences() | Save NVS parameters | Writes all operating parameters plus 6 messages to NVS. Opens and closes the namespace to guarantee flash flush.
calculateMorseTimi ng() | Calculate Morse timing | Calculates ditLength, dahLength, elemSpace, charSpace, wordSpace in milliseconds from current WPM. If Farnsworth is active, calculates extended spacing separately.

## 3. Main Loop and LVGL

Routine | Short description | Detail
loop() | Main loop Core 1 | Calls lv_timer_handler() to update LVGL GUI, processDisplayQueue() to apply messages from the display queue, sdPlayerTask() for SD player, checkSerialBle() for incoming BLE data, and updateClockLVGL() every second for the clock.
processDisplayQueu e() | Apply display messages | Extracts messages from displayQueue produced by morseTask and updates corresponding LVGL labels (TX LED, text bars, WPM, VOL, FREQ, mode).
lvgl_updateTxLed() | Update TX LED | Changes the colour of the circular LED on the display: green when transmitting, dark grey when idle.
lvgl_appendTxBar() | Append char to text bar | Appends a character to the scrolling blue bar (L3). When L3 is full, scrolls text to rows L2 and L1.
lvgl_clearAll() | Clear display | Clears all three text bars and status labels on the display.
updateClockLVGL() | Update clock | Reads ESP32 system time and updates ui_LabelClock label every second. Label border is green if year > 1970 (RTC set), red otherwise.
my_disp_flush() | LVGL display flush | LVGL callback: transfers the rendered buffer to the ILI9341 display via tft.pushColors().
my_touchpad_read() | LVGL touch read | LVGL callback: reads raw XPT2046 coordinates, maps them to screen coordinates 320×240 via calibration, returns pressed/released state.

## 4. Morse Task (Core 0)

Routine | Short description | Detail
morseTask() | Main keyer task | Runs in a loop on Core 0. Waits 2 seconds at startup (FIX-4, avoids spurious 'E'). Then continuously calls checkPaddle() and sendFromBuffer(). Also manages automatic beacon and contest mode.
checkPaddle() | Read paddle state | Reads PADDLE_DIT and PADDLE_DAH pins. Based on mode (Iambic A/B, Manual, Auto)

| | decides whether to start DIT or DAH transmission. Updates dit/dahPaddleFlag and decodes the Morse binary tree for display.
paddle_beginDIT() | Start DIT transmission | Activates DAC (sidetone), raises MORSE_OUT (PTT), waits DIT duration via morseDelay(), then deactivates DAC and lowers MORSE_OUT. Sends '.' symbol to display and updates decoding.
paddle_beginDAH() | Start DAH transmission | Same as paddle_beginDIT() but for DAH duration (ditLength × dahRatio).
paddle_morse_On() | Activate carrier (paddle) | Enables ESP32 DAC and raises MORSE_OUT. Used by manual key.
paddle_morse_Off() | Deactivate carrier (paddle) | Disables DAC and lowers MORSE_OUT.
paddleTimer() | Inter-element timing | Calculates timeout for current Morse character decoding. If inter-character time elapses without new elements, marks character as ready for decoding.
sendFromBuffer() | Transmit from buffer | Extracts characters from the buffer string and passes them to sendMorseChar(). Recognises <XX> prosign syntax. Updates text bar on display. Signals idle at end of buffer.
sendMorseChar(char c) | Transmit one Morse char | Converts ASCII character to DIT/DAH sequence via internal Morse table. Calls morseToneOn() and morseToneOff() for each element, respecting calculated timings. Also handles prosign characters without inter-character space.
morseToneOn(ms) | Activate tone for ms | Enables ESP32 DAC at set tone/volume, raises MORSE_OUT (PTT), waits ms via morseDelay(). Sends DISP_TX_LED ON to displayQueue.
morseToneOff(ms) | Deactivate tone for ms | Disables DAC, lowers MORSE_OUT, waits ms via morseDelay(). Sends DISP_TX_LED OFF.
morseDelay(ms) | Non-blocking delay | Waits ms milliseconds using morseTimerTick counter (1 kHz HW timer). Yields CPU every 1 ms with vTaskDelay(1) instead of blocking delay().
onMorseTimer() | HW timer ISR | IRAM_ATTR interrupt service routine: increments morseTimerTick every millisecond.
addToBuffer(str) | Add text to buffer | Appends string str to the transmission buffer, adding a separator space. Thread-safe via LOCK/UNLOCK.
clearBuffer() | Clear buffer | Clears the transmission buffer and sends DISP_CLEAR to the display queue.
sendProsign(str) | Transmit prosign <XX> | Transmits prosign characters without inter-character space between them, as per international telegraph standard.

## 5. Serial Task (Core 0)

Routine | Short description | Detail

serialTask() | Serial task Core 0 | Continuously reads USB serial port (Serial). In K3NG mode calls checkSerial(); in WinKey mode calls checkSerialWinkey(). Low priority (1) to avoid interfering with the keyer.
checkSerial() | K3NG command parser | Interprets K3NG commands arriving from serial port. Commands start with '\' followed by a letter. Handles: \W (set WPM), \F (set frequency), \Z (set time), \A-\Z (memories), \J (reset touch calibration), \Y (sidetone freq), \X (HSCW toggle), \E (extended display), and all configuration commands. Normal text is queued to the transmission buffer.
checkSerialWinkey( ) | WinKey protocol parser | Interprets the WinKey 2.x binary protocol. Handles host open (0x00), speed commands (0x02), mode register (0x0E), text (0x04), tune (0x0B), PTT timing, and all commands defined in the WK3 datasheet.
checkSerialBle() | BLE command parser | Processes data received in bleRxBuffer. Applies the same parser as checkSerial() or checkSerialWinkey() depending on the active mode.
sendStatus() | Send serial status | Responds to \S command by sending current state to serial port: WPM, freq, vol, mode, beacon, BLE, SD.
sendHelp() | Send serial help | Prints the list of available commands to serial port.
sendContestMsg() | Transmit contest message | Queues contest message with progressive counter to transmission buffer, then increments counter.

## 6. BLE (Bluetooth Low Energy)

Routine | Short description | Detail
bleSetup() | Initialise BLE | Initialises BLEDevice with name 'VK2IDL_Morse', creates BLE server and Nordic UART service (NUS) with TX and RX characteristics. Registers MyServerCallbacks and MyCallbacks.
bleInit() | Start BLE advertising | Makes the device visible to BLE clients. Sets device name explicitly in primary advertising payload (fix v7.1.3 — resolves 'unnamed' on Android). Moves service UUID to scan response. Updates BLE button on screen.
bleStop() | Stop BLE | Stops advertising and disconnects clients. Releases BLE resources.
bleSend(str) | Send string via BLE | Sends string str to connected BLE client via TX characteristic. Does nothing if no client is connected or BLE is disabled.
bleSendLong(str) | Send long string via BLE | Sends long strings in chunked 20-byte packets with inter-packet delay. Used for \H, \V, \I, \P list responses.
updateBleButton() | Update BLE UI button | Updates BLE button text and colour in Settings tab based on state: OFF / ADV / CONN.

MyServerCallbacks | BLE connection callback | C++ class: onConnect() sets bleClientConnected=true and signals UI update. onDisconnect() restarts advertising if BLE is enabled.
MyCallbacks | BLE receive callback | C++ class: onWrite() queues received bytes in bleRxBuffer for processing in loop().

## 7. LVGL User Interface

Routine | Short description | Detail
createUI() | Create main tabview | Creates tabview with 5 tabs: Morse 1, Morse 2, SD, Settings, Spare. Calls creation function for each tab.
createTabMorse1() | Create Morse 1 tab | Builds main tab layout: scrolling text areas L1/L2/L3, message buttons (CQ, NAME, ANT, QTH, RST, TEST), CLEAR, STOP, TUNE, BEACON, CONTEST, MACRO, KEYER MODE buttons, WPM/VOL/FREQ controls.
createTabMorse2() | Create Morse 2 tab | Alternative keyer layout with same functionality but optimised arrangement for operating use.
createTabSD() | Create SD player tab | Builds SD panel: file/info/text labels, OPEN/PLAY/PAUSE/STOP buttons, WPM label. Updates labels with current SD card state.
createTabSettings( ) | Create Settings tab | Builds Settings panel: Ratio, Weight, Pad Reverse, Beacon, Contest, Farnsworth, SD Log, QRSS, BLE, Protocol (K3NG/WinKey), Recalibrate buttons.
createTabSpare() | Create Spare tab | Development tab with HSCW (High Speed CW) functionality and future controls.
createCommonContro ls() | Create common controls | Creates WPM+/-, VOL+/-, FREQ+/- controls, TX LED, Iambic Mode button — present identically in both Morse 1 and Morse 2 tabs.
createLogAreas() | Create scrolling text areas | Creates three LVGL labels L1, L2, L3 (Morse text bars) on a parent panel. L3 is the active blue bar (large font), L2 and L1 are black (small font).

## 8. Button Event Handlers

Handler | Trigger | Action
onCQ/Name/AntRig/Qth/ Rst/Test() | Tap on message button | Adds preset message to buffer. Long-press opens showMsgEditor() for editing.
onMacro() | Tap MACRO | Adds macroMessage to buffer. Long-press opens editor to modify macro.
onStop() | Tap STOP | Sets stopRequested=true. morseTask interrupts transmission at end of current element

| | and clears buffer.
onClear() | Tap CLEAR | Calls clearBuffer() and sends DISP_CLEAR to display queue.
onTune() | Tap TUNE | Toggles TUNE mode: sends continuous carrier + PTT ON. Updates UI.
onBeacon() | Tap BEACON | Toggles automatic CQ message beacon transmission at set interval.
onContest() | Tap CONTEST | Opens Contest popup to set starting counter number. Toggles contest mode.
onKeyerMode() | Tap KEYER/BUFFER | Toggles between KEYER mode (transmits immediately from paddle) and BUFFER mode (accumulates in buffer before transmitting).
onIambicMode() | Tap iambic mode | Cycles between modes: Iambic A → Iambic B → Manual → Auto. Updates label and saves preference.
onWpmUp/Down() | Tap +/- WPM | Increments/decrements WPM by 1 (range 5-100). Recalculates Morse timing and updates display.
onVolUp/Down() | Tap +/- VOL | Changes DAC attenuation level (0=mute, 4=max). Updates display and hardware DAC.
onFreqUp/Down() | Tap +/- FREQ | Modifies sidetone frequency by 50 Hz (range 300-1200 Hz). Updates DAC.
onRatio() | Tap RATIO | Opens showPopupRatio(): slider to modify dahRatio (2.0-4.5).
onWeight() | Tap WEIGHT | Opens showPopupWeight(): slider to modify spacing_Weight.
onPadRev() | Tap PAD REV | Opens showPopupPadRev(): toggle to swap DIT/DAH on paddle.
onFarnsworthToggle() | Tap Farnsworth | Toggles Farnsworth. If activated, opens showPopupFarnsworth() to set spacing WPM.
onQrssToggle() | Tap QRSS | Cycles QRSS modes: OFF → 3s → 6s → 10s → 30s per DIT. Recalculates qrssDitMs.
onBleToggle() | Tap BLE | Toggles Bluetooth Low Energy. Calls bleInit() or bleStop().
onProtocolToggle() | Tap K3NG/WinKey | Toggles serial protocol between K3NG (115200 baud) and WinKey 2.x (1200 baud). Updates winkeyMode and reinitialises Serial at correct baud rate.
onSdLogToggle() | Tap SD Log | Toggles SD logging. If activated, calls sdLogInit() to open/create log file.
onRecalibrate() | Tap Recalibrate | Clears touch calibration from NVS and reboots device to start guided calibration procedure.
showMsgEditor(idx) | Long-press on message | Opens overlay with LVGL textarea pre-loaded with current message and virtual keyboard. SAVE and CANCEL buttons close the editor.
onMsgEditorSave() | Tap SAVE in editor | Reads text from textarea, updates global message variable, performs NVS flush with end()/begin()/putString()/end()/begin() to guarantee persistence.

## 9. Popups and Dialogs

Routine | Short description | Detail
createPopupBase(ti tle) | Create popup structure | Creates a semi-transparent centred modal panel with title. Used as base by all popups.
closePopup() | Close active popup | Deletes popupBox and resets all current popup widget references.
showPopupRatio() | DAH Ratio popup | Shows slider to adjust dahRatio with -/+ buttons, current value label, SAVE button.
showPopupWeight() | Spacing Weight popup | Same as showPopupRatio() but for spacing_Weight.
showPopupBeacon() | Beacon Interval popup | Allows setting beacon interval in seconds (10-600).
showPopupContest() | Contest Counter popup | Allows setting the contest counter starting number.
showPopupFarnswort h() | Farnsworth WPM popup | Shows two labels (Effective WPM and Chars WPM) and slider for farnsworthWPM. Values update in real time while moving the slider.
showPopupHscw(wpm) | HSCW Speed popup | Slider to set HSCW (High Speed CW) speed. Called from Spare tab.

## 10. SD Card and Player

Routine | Short description | Detail
sdScanFiles(target ) | Scan SD for .txt files | Reads SD card root directory and populates sdFileList[] with found .txt file names (max 20). If target is specified, repositions cursor on that file.
sdLoadFile(filenam e) | Load file from SD | Opens specified .txt file, reads all content into sdText, resets sdCharIndex=0 and updates text preview labels.
sdOpenFilePopup() | Open file list popup | Creates popup with scrollable list of available .txt files on SD. Tap on a file calls sdLoadFile().
sdCloseFilePopup() | Close file list popup | Deletes sdPopup LVGL object.
sdPlayerTask() | SD player task (in loop) | Called every loop() cycle. If sdState==SD_PLAYING, extracts next character from sdText and adds it to Morse transmission buffer, advancing sdCharIndex. When end of file reached, sets sdState to SD_IDLE.
sdUpdateFileLabel( ) | Update SD file label | Shows current file name and text length on SD tab.
sdUpdateInfoLabel( ) | Update SD info label | Shows current frequency and volume in SD tab.

sdUpdateWpmLabel() | Update SD WPM label | Updates WPM label in SD tab with current value.
sdUpdateButtons() | Update SD button state | Enables/disables PLAY/PAUSE/STOP buttons based on sdState (IDLE/PLAYING/PAUSED).
sdLogInit() | Initialise SD log | Creates or opens a CSV log file on SD with name based on uptime. Writes header with date, WPM, frequency.
getUptimeString() | Return uptime string | Calculates and returns time elapsed since boot in HH:MM:SS format.

## 11. Touch Calibration (NEW v7.1.4)

Routine | Short description | Detail
runTouchCalibratio n() | Run guided calibration | Runs the 4-point interactive calibration procedure. Displays crosshair at each corner in sequence. Waits for user touch via waitTouchPoint(). Calculates and validates the 4 calibration values. Shows ACCEPT/RETRY screen. If accepted (or timeout 10s), saves to NVS namespace 'touch_cal'.
waitTouchPoint(x,y ,label) | Wait for touch on point | Displays crosshair at coordinates (x,y) with on-screen instruction label. Waits for a touch event from XPT2046 with timeout. Serial 'R' escape cancels. Returns raw ADC coordinates.
loadTouchCalibrati on() | Load calibration from NVS | Reads cal_x_min, cal_x_max, cal_y_min, cal_y_max from 'touch_cal' NVS namespace. Validates range (x_min 100-1000, x_max 3000-4095, excursion ≥ 2000). If valid, applies to touch mapping. If invalid or absent, uses hardcoded defaults.
saveTouchCalibrati on() | Save calibration to NVS | Writes the 4 calibration values to 'touch_cal' NVS namespace with putInt(). Opens and closes namespace to guarantee flash flush.
resetTouchCalibrat ion() | Reset calibration (\J) | Clears 'touch_cal' NVS namespace and triggers device reboot to restart guided calibration. Called by K3NG \J command and onRecalibrate() handler.

## 12. Utility Functions

Routine | Short description | Detail
postDisplay(type, val) | Send message to display queue | Thread-safe inline: builds a DisplayMsg and sends it to displayQueue without blocking. If queue is full, message is discarded.
postDisplayChar(c) | Send char to text bar | Specialisation of postDisplay() for type DISP_TX_BAR: sends a single character to the blue text bar.
updateStatusLabels | Update status labels | Updates WPM, VOL, FREQ labels in both Morse 1 and Morse 2 tabs.

()

getModeName() | Return mode name | Returns current keyer mode string: 'IAMB-A', 'IAMB-B', 'MANUAL', 'AUTO'.
calculateDitDurati on() | Calculate DIT duration ms | Returns DIT duration in milliseconds at current WPM: 1200/WPM.
volumeUiLevel(v) | Convert volume UI level | Inline: converts internal DAC level (0-4) to screen display value (inverted: 0=mute, 4=max).
getQrssModeString( mode) | QRSS mode string | Returns text representation of active QRSS mode: 'OFF', '3s', '6s', '10s', '30s'.

IW1RMM (Mauri) — IW1RMM CW Encoder — Based on VK2IDL firmware — Firmware Analysis v7.1.4 — March 2026

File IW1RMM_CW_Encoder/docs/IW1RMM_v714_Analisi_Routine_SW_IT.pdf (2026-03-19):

# IW1RMM CW Encoder — Analisi Routine Software

### Versione firmware: v7.1.4 | Hardware: ESP32-2432S028R (CYD) | Autore: IW1RMM

# 1. Architettura Generale

Il firmware v7.1.4 adotta un'architettura FreeRTOS multi-task con separazione netta tra logica Morse (Core 0) e rendering LVGL (Core 1). La comunicazione inter-task avviene tramite una coda displayQueue e un mutex xMutex.

Task / Contesto | Core | Stack | Priorità | Funzione principale
morseTask | 0 | 8192 byte | 2 | Keyer paddle, buffer TX, beacon, tune
serialTask | 0 | 4096 byte | 1 | Parser K3NG e Winkey da Serial
loop() / LVGL | 1 | Arduino default | — | lv_timer_handler(), processDisplayQueue(), sdPlayerTask()
bleSetupTask | 1 | 8192 byte | 1 | Init BLE stack (one-shot, si auto-elimina)
Meccanismo | Tipo | Dimensione / Note
displayQueue | QueueHandle_t | 64 messaggi DisplayMsg — morseTask→loop()
xMutex | SemaphoreHandle_t | Mutex binario — protegge buffer, wpm, flags condivisi
morseTimer | hw_timer_t 1 kHz | ISR incrementa morseTimerTick ogni 1 ms
morseDelay(ms) | Busy-wait su tick HW | Usata in morseTask al posto di delay()

# 2. Setup e Inizializzazione

## 2.1 setup()

Sequenza di inizializzazione eseguita una sola volta su Core 1 (loopTask Arduino).

Step | Operazione | Note v7.1.4
0 | Serial.begin(115200) | Serial1.end() preventivo per evitare conflitti

SD | SPI.begin() + SD.begin(SD_CS) | SD inizializzata PRIMA di tft.begin() per evitare reset bus
1 | Preferences begin/load | Namespace 'cyd-morse'; carica wpm, freq, vol, ratio, weight, messaggi
2 | setupPins() | MORSE_OUT=27 LOW, PADDLE_DAH=22 PULLUP, PADDLE_DIT=35, DAC pin 26, TFT_BL=21 HIGH
3 | setupLVGL() | lv_init(), tft.begin(), rotation=1, draw_buf 320×10, registra disp e indev driver
4 | setupTouch() | Carica calibrazione da NVS 'touch_cal'; se assente usa hardcoded (220/3730/387/3763)
4b | runTouchCalibration() | Eseguita solo se NVS 'calibrated'==false (primo avvio o dopo reset \J)
5 | setupTimer() | timerBegin(1000000), alarm 1ms, ISR onMorseTimer()
6 | createUI() | Crea tabview + 5 tab LVGL
7 | bleSetup() | Lancia bleSetupTask su Core 1 (one-shot)
7b | setupTasks() | Lancia morseTask (Core 0, pri 2) e serialTask (Core 0, pri 1)

## 2.2 setupPins()

Pin | GPIO | Direzione | Stato iniziale
MORSE_OUT (PTT/Key) | 27 | OUTPUT | LOW
PADDLE_DAH | 22 | INPUT_PULLUP | —
PADDLE_DIT | 35 | INPUT | —
TFT_BL (Backlight) | 21 | OUTPUT | HIGH
DAC Audio | 26 | DAC (DacESP32) | disable()

## 2.3 setupLVGL()

Inizializza LVGL 8.x con display ILI9341 320×240 e touch XPT2046. Il buffer di disegno occupa 320×10 pixel. La callback my_disp_flush() usa TFT_eSPI::pushColors(); my_touchpad_read() usa XPT2046_Touchscreen su bus HSPI con mappatura coordinate calibrate.

## 2.4 setupTouch() — NOVITÀ v7.1.4

Carica i parametri di calibrazione touch dal namespace NVS 'touch_cal'. Se non presenti, usa i valori hardcoded di default (x_min=220, x_max=3730, y_min=387, y_max=3763). Inizializza il bus HSPI e la libreria XPT2046_Touchscreen con rotation=1.

## 2.5 setupTimer()

Configura un hardware timer a 1 MHz con alarm ogni 1000 tick (= 1 ms). La ISR onMorseTimer() (in IRAM) incrementa il contatore morseTimerTick usato da morseDelay() per delay non-bloccanti in morseTask.

# 3. Calibrazione Touch — NOVITÀ v7.1.4

La v7.1.4 introduce una calibrazione touch interattiva a 4 punti con persistenza NVS in un namespace separato ('touch_cal'), indipendente dalle preferenze principali ('cyd-morse').

Funzione | Firma | Descrizione
touchCalSave() | touchCalSave(int xmin, xmax, ymin, ymax) | Salva 4 valori + flag 'calibrated'=true nel namespace NVS 'touch_cal'
touchCalLoad() | bool touchCalLoad(int &xmin, &xmax, &ymin, &ymax) | Carica valori da NVS. Ritorna true se calibrated==true, false altrimenti
touchCalReset() | void touchCalReset() | Cancella l'intero namespace 'touch_cal' (p.clear()). Usata da onRecalibrate() e comando \J
drawCross() | void drawCross(int x, int y, uint16_t color) | Disegna croce di calibrazione (+15px) + cerchio r=5 sul TFT raw (senza LVGL)
waitTouch() | bool waitTouch(int &rawX, int &rawY) | Attende tocco XPT2046 raw. Timeout 10s → false. Escape via Serial 'R' → false
runTouchCalibration() | void runTouchCalibration() | Procedura completa: 4 punti (TL/TR/BR/BL), validazione range, conferma 10s, save + ESP.restart()

## 3.1 runTouchCalibration() — Flusso

Fase | Descrizione
Display istruzioni | Schermo nero con testo guida e avviso escape Serial 'R'
4 punti sequenziali | TL(20,20) → TR(300,20) → BR(300,220) → BL(20,220). Per ogni punto: drawCross verde, waitTouch(), conferma rossa
Calcolo valori | xmin=media(TL.x, BL.x), xmax=media(TR.x, BR.x), ymin=media(TL.y, TR.y), ymax=media(BR.y, BL.y)
Validazione range | xmin 100-1000, xmax 3000-4095, ymin 100-1000, ymax 3000-4095, delta>2000 su entrambi gli assi
Conferma | Mostra valori calcolati, attende tocco o timeout 10s (auto-conferma)

Salvataggio | touchCalSave() → ESP.restart() per applicare immediatamente
Fallback | Se annullato/timeout/valori invalidi: ritorna senza salvare, setupTouch() usa hardcoded

# 4. Preferenze NVS

Funzione | Namespace | Operazione
loadPreferences() | 'cyd-morse' (read-only) | Carica wpm, freq, vol, ratio, weight, paddleReversed, beaconIntervalSec, contestCounter, msg0-msg5
savePreferences() | 'cyd-morse' (r/w) | Salva gli stessi parametri. Chiamata ad ogni modifica da UI o seriale
loadMemories() | 'cyd-morse' (read-only) | Carica k3ngMem[0..25] con chiavi 'mem_A'..'mem_Z'
saveMemory(int idx) | 'cyd-morse' (r/w) | Salva una singola memoria K3NG (chiave 'mem_X') — chiamata dopo ogni \P
touchCalSave/Load/Reset() | 'touch_cal' separato | Namespace dedicato — p.clear() non tocca 'cyd-morse'

# 5. Interfaccia Utente LVGL

L'UI è strutturata in un tabview con 5 tab. Tutti gli oggetti LVGL vengono creati su Core 1 in setup() e aggiornati esclusivamente nel loop() tramite la coda displayQueue.

Tab | Funzione createTab*() | Contenuto principale
Morse 1 | createTabMorse1() | Controlli WPM/VOL/FREQ, LED TX, KEY mode, pulsanti CQ/NAME/ANT-RIG/CLEAR/QTH/RST/TEST/KEYER, aree log L1/L2/L3
Morse 2 | createTabMorse2() | Stessi controlli comuni + RATIO/WEIGHT/TUNE/MACRO/PAD.REV/BEACON/CONTEST/S TOP
SD | createTabSD() | Info file, 5 righe testo, SPD-/WPM/SPD+, PLAY/PAUSE/STOP, popup lista file FILE
Settings | createTabSettings() | Mode K3NG/WINKEY, Calibra Touch, Farnsworth, SD LOG, QRSS, Orologio, BLE
Spare | createTabSpare() | Placeholder 'Reserved for future features' (previsto Trainer CW)

## 5.1 createCommonControls()

Crea i controlli comuni a Tab Morse 1 e Tab Morse 2: bottoni WPM -/+, VOL -/+, FREQ -/+, LED TX circolare (grigio/rosso), label TX, bottone IAMBIC MODE. Accetta puntatori di output per i riferimenti agli oggetti specifici di ogni tab.

## 5.2 createLogAreas()

Crea le tre aree di testo in fondo al tab (Y=116 e Y=170): due label nere (L1 alta, L2 bassa, font montserrat_12, 316px width, clip, align right) e una label blu (L3 barra TX, font montserrat_16, sfondo 0x0000FF, testo giallo). Aggiornate tramite lvgl_appendTxBar() e lvgl_clearAll().

## 5.3 Display Queue — processDisplayQueue()

Chiamata ogni ciclo di loop(). Svuota la coda displayQueue ricevendo messaggi DisplayMsg e aggiornando gli oggetti LVGL corrispondenti. Garantisce che tutte le chiamate lv_* avvengano su Core 1.

Tipo messaggio | Payload | Azione LVGL
DISP_TX_LED | u8 (0/1) | lvgl_updateTxLed(): colore LED rosso/grigio su entrambi i tab
DISP_TX_BAR | char | lvgl_appendTxBar(): scroll L3→L2→L1 e append carattere
DISP_CLEAR | — | lvgl_clearAll(): reset stringBuf_L1/L2/L3, label='Ready'
DISP_WPM | i32 | lv_label_set_text_fmt su labelWpm1 e labelWpm2
DISP_VOL | i32 | Aggiorna VOL label (con 'M' se mute)
DISP_FREQ | i32 | Aggiorna FRQ label su entrambi i tab
DISP_IAMBIC_MODE | i32 (KeyerMode) | Aggiorna testo e colore btnIambicMode1/2
DISP_KEYER_LABEL | i32 (0/1) | KEYER (giallo) o BUFFER (verde) su btnKeyerMode
DISP_TUNE | u8 | Colore btnTune: rosso=ON, grigio=OFF
DISP_BEACON | u8 | Colore btnBeacon: rosso=ON, grigio=OFF
DISP_FARNSWORTH | i32 (wpm o 0) | Label e colore btnFarnsworth: verde=ON, grigio=OFF

## 5.4 lvgl_appendTxBar(char c)

Implementa lo scorrimento del ticker a 3 righe identico al vecchio sketch VK2IDL originale. L3 (blu, max 32 char) scorre verso L2 (nera, max 42 char) che scorre verso L1 (nera, max 42 char). I nuovi caratteri entrano da destra. Aggiorna tutte e 6 le label (2 tab × 3 righe) ad ogni carattere.

# 6. Popup e Editor Messaggi

Funzione | Trigger | Descrizione
createPopupBase(title) | Interna | Crea overlay 320×240 semitrasparente + box 240×140 con bordo blu. Ritorna il box come parent
closePopup() | Bottoni SAVE/CANCEL | lv_obj_del(popupBox), azzera popupBox e popupValueLabel
showPopupRatio() | onRatio() | Popup ±0.1 per dahRatio (2.5–4.0). Save aggiorna dahRatio e ricalcola timing
showPopupWeight() | onWeight() | Popup ±0.05 per spacing_Weight (0.80–1.20)
showPopupPadRev() | onPadRev() | Toggle NORMAL/REVERSED con anteprima colore
showPopupBeacon() | onBeacon() short press | Popup ±10s per beaconIntervalSec (10–300s)
showPopupContest() | onContest() 400-1000ms | Popup ±1 per contestCounter (1–999)
showPopupFarnsworth() | onFarnsworthToggle() se OFF | Popup ± WPM effettivo Farnsworth. Mostra 'Effective: N WPM' e 'Chars: M WPM'
showPopupHscw(int wpm) | onWpmUp() se wpm==60 o onWpmDown() se wpm>60 | Popup slider 60–100 WPM con snap ogni 5 WPM per modalità HSCW
showMsgEditor(int idx) | Long press (>800ms) su CQ/NAME/ecc | Editor fullscreen 320×240 con textarea + tastiera LVGL uppercase. Save con NVS flush garantito

# 7. Event Handlers UI

Handler | Evento | Azione
onWpmUp/Down() | CLICKED | Se QRSS attivo: blocca. Se wpm==60 e Up: showPopupHscw(60). Se wpm>60 e Down: showPopupHscw(). Altrimenti ±1 WPM (5–60)
onVolUp/Down() | CLICKED | Scala volumeLevel (0–4) e toneVol (DAC_CW_SCALE). 0=mute
onFreqUp/Down() | CLICKED | ±50 Hz audioTone (300–1200 Hz)
onIambicMode() | CLICKED | Cicla IAMBIC_A→IAMBIC_B→MANUAL→AUTO_MODE→IAMBI C_A. Aggiorna testo e colore pulsante direttamente (siamo su Core 1)
handleMsgBtn() | PRESSED/ RELEASED | Short press (<800ms): buffer+=msg+spazio. Long press (≥800ms): showMsgEditor(idx)

onClear() | CLICKED | buffer='', stopRequested=true, isBufferMode=false, postDisplay(DISP_CLEAR)
onTune() | CLICKED | Toggle isTuneMode. Il morseTask gestisce DAC; qui solo colore pulsante
onStop() | CLICKED | stopRequested=true, beaconActive=false, isTuneMode=false, buffer='', reset tutti i flag paddle. digitalWrite(MORSE_OUT,LOW), dac1.disable()
onRecalibrate() | CLICKED | touchCalReset() + delay(500) + ESP.restart()
onProtocolToggle() | CLICKED | Toggle winkeyMode. Se Winkey: Serial.begin(1200). Se K3NG: Serial.begin(115200). Aggiorna label e colore btnProtocol
onFarnsworthToggle() | CLICKED | Se OFF→showPopupFarnsworth(). Se ON→disabilita e ricalcola timing
onSdLogToggle() | CLICKED | Toggle sdLoggingEnabled. Se ON: sdLogInit(). Se OFF: chiude logFile con footer
onQrssToggle() | CLICKED | Cicla QRSS_OFF→3→6→10→30→OFF. Calcola qrssDitMs=mode*1000ms. Blocca WPM se HSCW
onBleToggle() | CLICKED | Se ON→bleStop(). Se OFF e stack pronto→bleInit(). Se stack non pronto→ESP.restart()
onBeacon() | PRESSED/ RELEASED | Se beacon attivo→stop. Se held≥800ms→avvia beacon. Se short→showPopupBeacon()
onContest() | PRESSED/ RELEASED | Long(≥1s)→sendContestMsg()+increment. Med(400-1000ms)→showPopupContest(). Doppio tap rapido→reset a 1

# 8. Logica Morse

## 8.1 calculateMorseTiming()

Ricalcola ditLength, dahLength, elemSpace, charSpace, wordSpace_ in base alla modalità attiva. Priorità: QRSS > Farnsworth > Normale/HSCW.

Modalità | ditLength | charSpace | wordSpace_
NORMALE/HSCW | 1200/wpm ms | dit×3×weight | dit×7×weight
FARNSWORTH | 1200/wpm ms (caratteri) | 1200/farnsworthWPM × 3×weight | 1200/farnsworthWPM × 7×weight
QRSS_3 | 3000 ms | 9000 ms | 21000 ms

QRSS_6 | 6000 ms | 18000 ms | 42000 ms
QRSS_10 | 10000 ms | 30000 ms | 70000 ms
QRSS_30 | 30000 ms | 90000 ms | 210000 ms

## 8.2 morseToneOn/Off(int ms)

morseToneOn(): se txEnabled=true → digitalWrite(MORSE_OUT,HIGH); se !muted → dac1.outputCW()+enable(); postDisplay(DISP_TX_LED,1); morseDelay(ms); poi spegne. morseToneOff(): solo morseDelay(ms). sendDit/sendDah() chiamano queste due funzioni con la durata appropriata.

## 8.3 sendFromBuffer()

Preleva il primo carattere dal buffer e lo trasmette. Gestisce i prosign in formato <XX>: cerca '>' con indexOf, estrae il codice e chiama sendProsign(). Per caratteri normali chiama sendMorseChar(). Aggiorna isBufferMode quando il buffer si svuota.

## 8.4 sendProsign(const String &code)

Invia la sequenza dit/dah del prosign senza inter-element space tra lettere (come da standard ITU). Supporta: AR, SK, BT, KN, AS, SN, HH, CL. Dopo il prosign aggiunge inter-char space. Mostra sul display come <AR> tramite postDisplayChar().

## 8.5 sendMorseChar(char c)

Trasmette un singolo carattere Morse. Gestisce A-Z, 0-9, e i simboli . , ? / = @ < >. Per spazio: solo morseToneOff(wordSpace-charSpace). Dopo ogni carattere: morseToneOff(charSpace) + postDisplayChar(c).

## 8.6 postDisplayChar(char c)

Helper che espande i caratteri prosign interni in etichette leggibili prima di inviarli alla coda: '+' → '<AR>', '=' → '<BT>', '~' → '<SK>', '^' → '<SN>', '&' → '<AS>', '(' → '<KN>'. Ogni carattere dell'etichetta viene inviato come messaggio DISP_TX_BAR separato.

# 9. Tabella mySet[] — Decodifica Paddle

Array di 121 elementi (indici 0–120) per la decodifica albero binario del paddle. morseNum parte da 1; ogni DIT fa morseNum<<=1, ogni DAH fa morseNum=(morseNum<<1)+1. Corrisponde all'ITU-R M.1677 completo con prosign.

Indice | Carattere | Codice Morse | Note

1 | ' ' (spazio) | root | Word space
2 | E | .
3 | T | -
34 | ^ (SN) | ...-. | SN understood
40 | & (AS) | .-... | AS wait
42 | + (AR) | .-.-. | Corretto in v7.1.2 (era 43)
49 | = (BT) | -...- | BT paragraph
54 | ( (KN) | -.--. | KN over to you
69 | ~ (SK) | ...-.- | SK end of work
76 | ? | ..-- ..
85 | . | .-.-.-
90 | @ | .--.-.
107 | ! | -.-.--
115 | , | --..--
120 | : | ---...

# 10. Paddle Keyer

Funzione | Descrizione
checkPaddle() | Dispatch in base a currentMode: MANUAL, AUTO_MODE, IAMBIC_A, IAMBIC_B. Disabilitata se qrssMode!=QRSS_OFF
paddle_morse_On() | digitalWrite(MORSE_OUT,HIGH) se txEnabled; dac1.enable() se !muted; postDisplay(DISP_TX_LED,1)
paddle_morse_Off() | digitalWrite(MORSE_OUT,LOW) se txEnabled; dac1.disable(); postDisplay(DISP_TX_LED,0)
paddle_beginDIT() | paddle_morse_On(), paddleStartTime=millis(), ditOnFlag=ditToneFlag=true
paddle_beginDAH() | paddle_morse_On(), paddleStartTime=millis(), dahOnFlag=dahToneFlag=true
paddleTimer() | Controlla scadenza DIT/DAH in base a ditLength/dahLength. Al termine: morseNum shift, paddleChar=true
printDitDah() | Se paddleChar e inter-char space ≥ 2×dit: decodifica mySet[morseNum], postDisplayChar(). Se echoEnabled: Serial+BLE

## 10.1 Modalità MANUAL — Fix v7.1.2

In MANUAL mode, checkPaddle() gestisce press/release del DIT paddle direttamente senza paddleTimer(). Al PRESS: paddle_morse_On() + paddleStartTime=millis() + ditToneFlag=true. Al RELEASE: paddle_morse_Off() + misura durata. Se dur < 2×ditLength → DIT (morseNum<<=1), altrimenti DAH (morseNum=(morseNum<<1)+1). paddleChar=true. La decodifica avviene in printDitDah() come per gli altri modi.

# 11. morseTask()

Eseguito su Core 0 con stack 8192 byte. Ciclo principale a 2ms con vTaskDelay(2). All'avvio: vTaskDelay(2000ms) per stabilizzazione pin paddle.

Fase nel loop | Condizione | Azione
TUNE | isTuneMode ON (prima volta) | DAC enable, MORSE_OUT HIGH, LED TX ON. Mantiene fino a isTuneMode=false
TUNE | isTuneMode OFF (appena disattivato) | DAC disable, MORSE_OUT LOW, LED TX OFF
PADDLE | buffer vuoto E beacon OFF E tune OFF | checkPaddle() + printDitDah()
BEACON | beaconActive E buffer vuoto | Se elapsed≥beaconInterval: buffer+=cqMessage
BUFFER TX | sempre | sendFromBuffer() (no-op se buffer vuoto)

# 12. serialTask() e Parser K3NG

Eseguito su Core 0, priorità 1, ciclo 1ms. Chiama checkSerial() che a sua volta chiama checkSerialBle() (BLE) e poi dispatcha su checkSerialWinkey() o parser K3NG in base a winkeyMode.

## 12.1 Comandi K3NG (checkSerial())

Comando | Parametro | Funzione
\S | nn (WPM) | Set/get WPM. Salva NVS
\F | nnn (Hz) | Set/get frequenza audio (300–1200 Hz)
\L | n (0–4) | Set/get volume. 0=mute
\W | nn (×100) | Set/get spacing weight (80–120 → 0.80–1.20)

\R | nnn (×100) | Set/get dah ratio (250–400 → 2.50–4.00)
\T | — | Toggle tune mode
\A/B | — | Set Iambic A / Iambic B
\K | — | Set Manual key
\O | — | Set Auto mode
\N | 0/1 | Paddle normal/reversed
\C | — | Clear buffer
\U | — | Query lunghezza buffer
\P | X[testo] | Save/query memoria K3NG A-Z. \P senza param: lista tutte
\M | X | Invia memoria K3NG A-Z
\Q | 0/3/6/10/30 | Set/get modalità QRSS
\Y | nn | Set/get Farnsworth WPM effettivo (0=disabilita)
\X | — | Toggle TX key output (sidetone only se OFF)
\E | — | Toggle echo paddle su Serial e BLE
\G | ±n | Set GMT offset (salva NVS)
\Z | 14 cifre | Set datetime GGMMAAAAHHMMSS → settimeofday()
\J | — | Reset calibrazione touch + ESP.restart()
\I/D | — | Stampa status completo
\V | — | Versione firmware
\H | — | Help completo
testo libero | — | Aggiunge caratteri al buffer morse

# 13. Winkey WK3 Protocol

Attivato da onProtocolToggle() con Serial.begin(1200). Il parser a macchina a stati checkSerialWinkey() gestisce la fase pre-open (solo Admin <00><02>) e post-open (tutti i comandi). Lo status byte viene inviato ogni 500ms o al cambiamento.

## 13.1 Comandi Winkey implementati (winkeyExecCmd)

Cmd | N param | Funzione
0x00 | 1 | Admin: subcmd 0x02=Host Open (risponde 0x23), 0x03=Host Close, 0x04=Echo,

| | 0x17→0x31
0x01 | 1 | Sidetone: mappa valore 1-10 a frequenza Hz secondo tabella WK spec
0x02 | 1 | Set WPM
0x03 | 1 | Set Weighting (10-90, 50=normale → spacing_Weight)
0x04 | 2 | PTT Lead/Tail (x10ms) → wkPttLead, wkPttTailTime
0x05 | 3 | Setup Speed Pot (minWPM, range, unused) → wkSpeedPotMin/Range
0x08 | 0 | Backspace: rimuove ultimo char dal buffer
0x09 | 1 | Set PinConfig → wkPinCfg
0x0A | 0 | Clear Buffer
0x0B | 1 | Key Immediate: 1=tune ON, 0=tune OFF
0x0C | 1 | Set HSCW WPM (60-100)
0x0D | 1 | Set Farnsworth WPM (0=off)
0x0E | 1 | Set Mode Register (bit 5-4: keyer mode, bit 3: paddle swap)
0x0F | 15 | Load Defaults: 15 parametri nell'ordine WK3 spec Table 13
0x10 | 1 | Set 1st Extension → wkFirstExtension
0x11 | 1 | Set Key Compensation → wkKeyComp
0x12 | 1 | Set Paddle Switchpoint → wkPaddleSP
0x15 | 0 | Request Status → winkeyUpdateStatus()
0x17 | 1 | Set Dit/Dah Ratio (33-66) → dahRatio
0x1C | 1 | Buffered Speed Change
0x1D | 1 | HSCW Speed Change buffered (60-100)
0x20-0x7E | — | ASCII text → buffer morse
0x80-0x85 | — | Prosign legacy encoding

## 13.2 winkeyBuildStatus()

Costruisce lo status byte WK3: tag MSB=110 (base 0xC0). Bit 4=WAIT (buffer>106 char), bit 3=0 (identifier), bit 2=BUSY (buffer non vuoto o key down), bit 1=BREAKIN (paddle attivo), bit 0=XOFF (buffer>106).

# 14. SD Card

Funzione | Descrizione
sdScanFiles(targetFile) | Scansiona '/' per file .txt (max 20). Se targetFile specificato, legge il contenuto direttamente durante la scansione (evita doppia apertura)
sdLoadFile(filename) | Chiama sdScanFiles(filename) per leggere testo. Normalizza spazi doppi. Aggiorna 5 label testo (50 char/riga). sdState=SD_IDLE
sdPlayerTask() | Chiamata da loop(). Se SD_PLAYING e buffer vuoto: invia UN carattere del testo al buffer morse. isBufferMode=true
sdOpenFilePopup() | Crea popup 300×210 con lista file scrollabile. Ogni bottone carica il file e chiude il popup
sdCloseFilePopup() | lv_obj_del(sdPopup)
sdUpdateFileLabel() | Aggiorna lblSdFile con nome file (max 20 char) e lunghezza testo
sdUpdateInfoLabel() | Aggiorna lblSdInfo con freq e vol correnti
sdUpdateWpmLabel() | Aggiorna lblSdWpm con WPM corrente
sdUpdateButtons() | Aggiorna colori PLAY/PAUSE/STOP in base a sdState
sdLogInit() | Crea/apre /morse_log.txt in append. Scrive header sessione
sdLogWrite(String msg) | Apre /morse_log.txt in append, scrive timestamp [dd/mm/yy HH:MM:SS] + msg, chiude

# 15. BLE (Bluetooth Low Energy)

Servizio Nordic UART (UUID 6E400001). TX characteristic con NOTIFY, RX characteristic con WRITE. Nome dispositivo 'VK2IDL_Morse'.

Funzione | Descrizione
bleSetup() | Lancia bleSetupTask su Core 1 (stack 8192). Task one-shot: init BLE stack, crea server/service/characteristics, vTaskDelete(NULL)
bleInit() | Configura advertising: nome 'VK2IDL_Morse' nel payload primario (fix v7.1.3), service UUID nello scan response. startAdvertising()
bleStop() | stopAdvertising(), bleEnabled=false, bleClientConnected=false
bleSend(String) | setValue()+notify() se bleEnabled e client connesso
bleSendLong(String) | Invia in chunk da 20 byte con vTaskDelay(10ms) tra i chunk
checkSerialBle() | Processa bleRxBuffer: accumula fino a \n, poi chiama processBleCommand()
processBleCommand(String | Parser comandi BLE: stessi comandi K3NG (\S, \F, \L, \P, \M, \I, \D, \Z, \G, \Y, \Q,

) | \X, \E, \A, \B, \K, \O, \T, \C, \U, \N, \V, \H). Testo libero → buffer morse
updateBleButton() | OFF=grigio, WAIT=blu, ON=verde su btnBle
MyServerCallbacks | onConnect: bleClientConnected=true, pending UI update. onDisconnect: false, restart advertising se ancora enabled
MyCallbacks | onWrite: aggiunge dati ricevuti a bleRxBuffer

# 16. Orologio RTC Software

Funzione | Descrizione
updateClockLVGL() | Chiamata da loop() ogni 1000ms. Legge time(NULL)+localtime(). Formato: data azzurra + ora gialla con recolor LVGL. Bordo verde smeraldo se anno>1970 (sincronizzato), rosso altrimenti
\Z GGMMAAAAHHMMSS | 14 cifre: imposta datetime via settimeofday(). Disponibile da Serial K3NG e BLE
\G ±n | Set gmtOffset (salvato NVS). Usato per visualizzazione locale

# 17. loop() — Ciclo Principale LVGL

Operazione | Frequenza / Condizione | Note
BLE deferred ops | Ogni ciclo se flag pending | bleUiUpdatePending, bleLogEnabledPending, bleLogDisabledPending
processDisplayQueue() | Ogni ciclo | Svuota coda e aggiorna oggetti LVGL
lv_timer_handler() | Ogni ciclo | LVGL ridisegna e processa touch
sdPlayerTask() | Ogni ciclo | Inietta carattere SD→buffer se SD_PLAYING e buffer vuoto
sdUpdateInfoLabel/WpmLabel() | Ogni 2000ms | Aggiorna info audio e WPM nel tab SD
updateClockLVGL() | Ogni 1000ms | Aggiorna label orologio nel tab Settings
delay(5) | Ogni ciclo | 5ms consigliati da LVGL per stabilità

# 18. Storico Modifiche

Versione Modifica principale

v6.9.0 | Base: keyer morse completo, BLE Nordic UART, SD player, Winkey 2.3, LVGL 5 tab, orologio, QRSS, Farnsworth, beacon, contest
v7.1.1 | Refactoring architettura multi-task FreeRTOS. BLE con BLEDevice nativo
v7.1.2 | Fix MANUAL mode: checkPaddle() gestisce press/release con misurazione durata DIT/DAH. mySet[] esteso a 121 elementi (ITU completo). Fix indice AR: 43→42. postDisplayChar() riscritta con espansione prosign <XX>
v7.1.3 | Fix BLE 'unnamed' su Android: bleInit() con BLEAdvertisementData::setName('VK2IDL_Morse') nel payload advertising primario; service UUID nello scan response
v7.1.4 | Calibrazione touch interattiva a 4 punti. Namespace NVS separato 'touch_cal'. Nuove funzioni: touchCalSave/Load/Reset(), runTouchCalibration(), drawCross(), waitTouch(). Comando \J per reset calibrazione via seriale. Protezioni: timeout 10s, escape 'R', validazione range, fallback hardcoded

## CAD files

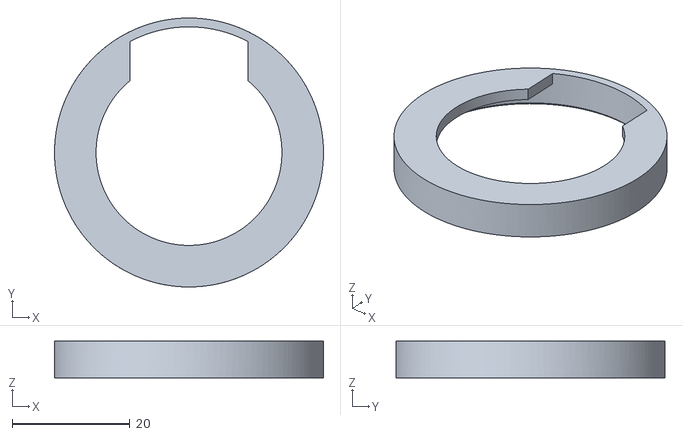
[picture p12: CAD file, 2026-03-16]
IW1RMM_CW_Encoder/hardware/Speaker-Cap.stl
45.6 x 45.6 x 6.25

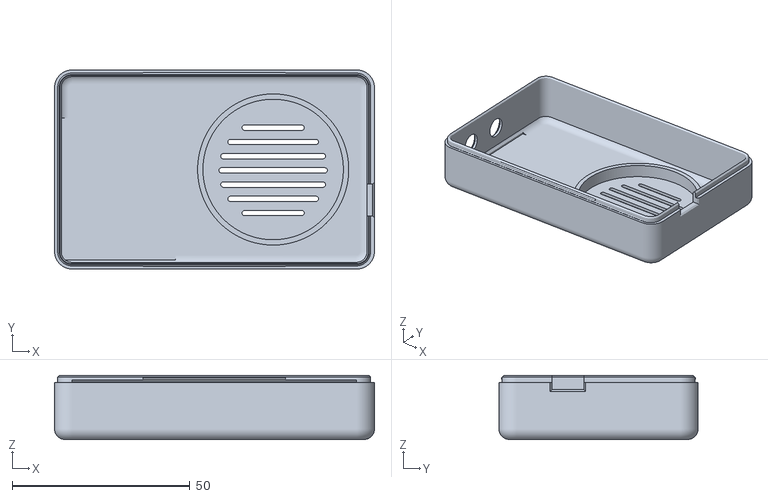
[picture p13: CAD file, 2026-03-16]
IW1RMM_CW_Encoder/hardware/Case-Rear_Panel.stl
90.0 x 56.0 x 18.0

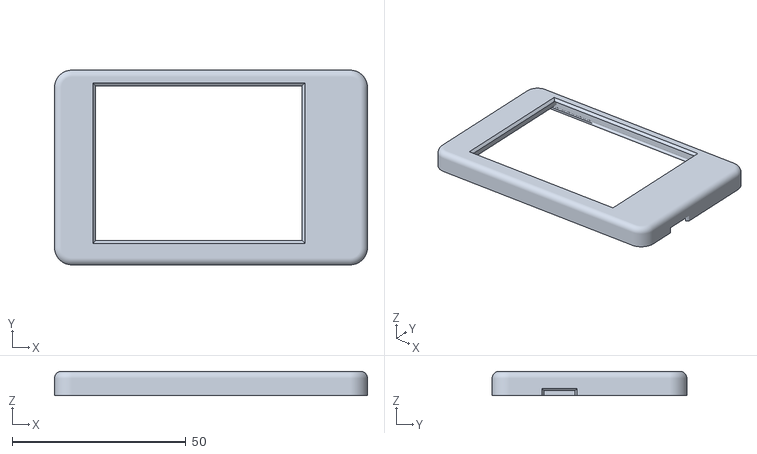
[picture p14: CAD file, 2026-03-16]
IW1RMM_CW_Encoder/hardware/Case-Front_Panel.stl
90.0 x 56.0 x 7.00

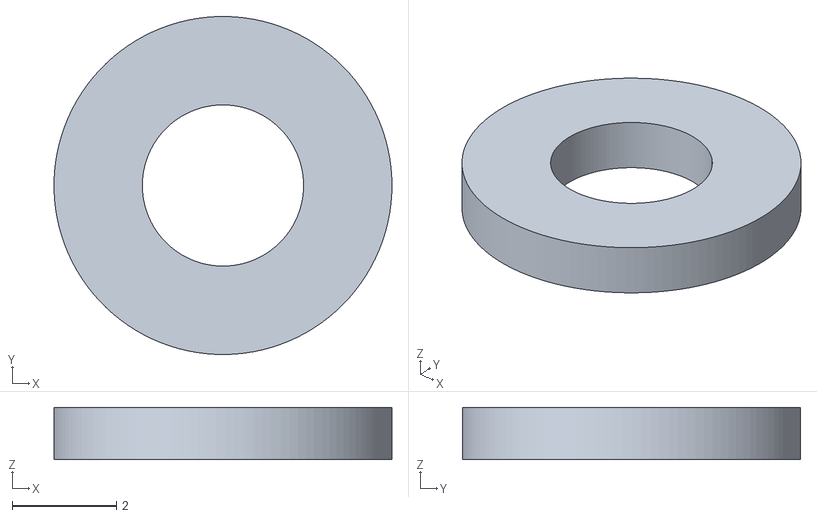
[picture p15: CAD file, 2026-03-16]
IW1RMM_CW_Encoder/hardware/Washer.stl
6.50 x 6.50 x 1.00

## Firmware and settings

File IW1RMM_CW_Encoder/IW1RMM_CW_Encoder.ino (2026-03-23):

/*
 * IW1RMM CW Morse Encoder - LVGL Edition
 * Version: Version: 7.1.5  (sketch file: _715) - Touch calibration interactive, ITA comments optimized
 * Hardware: ESP32 CYD (ESP32-2432S028R)
 * Display: ILI9341 320x240 with XPT2046 Touch
 *
 * Modified by IW1RMM (Mauri) - 2026
 * Based on VK2IDL "Ian" original work
 */

#include <lvgl.h>
#include <TFT_eSPI.h>
#include <SPI.h>
#include <SD.h>
#include <XPT2046_Touchscreen.h>
#include <Preferences.h>
#include "DacESP32.h"
#include <BLEDevice.h>
#include <BLEServer.h>
#include <BLEUtils.h>
#include <BLE2902.h>
#include "esp_bt.h"
#include "nvs_flash.h"
// BLE UUIDs per UART service (standard Nordic UART)
#define BLE_SERVICE_UUID           "6E400001-B5A3-F393-E0A9-E50E24DCCA9E"
#define BLE_CHARACTERISTIC_UUID_RX "6E400002-B5A3-F393-E0A9-E50E24DCCA9E"  // RX dal client
#define BLE_CHARACTERISTIC_UUID_TX "6E400003-B5A3-F393-E0A9-E50E24DCCA9E"  // TX al client

// ============================================================================
// HARDWARE OBJECTS
// ============================================================================
DacESP32 dac1(GPIO_NUM_26);

// ============================================================================
// PIN DEFINITIONS
// ============================================================================
#define TFT_MOSI 13
#define TFT_SCLK 14
#define TFT_CS   15
#define TFT_DC   2
#define TFT_RST  -1
#define TFT_BL   21

#define XPT2046_IRQ  36
#define XPT2046_MOSI 32
#define XPT2046_MISO 39
#define XPT2046_CLK  25
#define XPT2046_CS   33
#define AUDIO_OUT    26
#define PADDLE_DAH   22
#define PADDLE_DIT   35
#define MORSE_OUT    27

// SD Card - pin nativi CYD (dedicati, fisicamente cablati alla SD sul PCB)
// I pin della SD NON sono condivisi con TFT (13/14/15) o RGB LED.
// La SD usa il bus SPI VSPI (stesso del touch), ma con CS separato (5 vs 33).
#define SD_CS   5   // Chip Select SD (unico per la SD card)
#define SD_MOSI 23  // Master Out Slave In
#define SD_MISO 19  // Master In Slave Out
#define SD_SCK  18  // Serial Clock

// ============================================================================
// EEPROM (Preferences) KEYS
// ============================================================================
#define PREF_RATIO      "ratio"
#define PREF_WEIGHT     "weight"
#define PREF_PAD_REV    "padrev"
#define PREF_BEACON_INT "bcnint"
#define PREF_WPM        "wpm"
#define PREF_VOL        "vol"
#define PREF_FREQ       "freq"
// Prefisso chiavi NVS per memorie K3NG A-Z
// La chiave sarà "mem_A", "mem_B", ... "mem_Z"
#define PREF_MEM_PREFIX "mem_"

// ============================================================================
// CONSTANTS
// ============================================================================
const int screenWidth  = 320;
const int screenHeight = 240;
const String VERSION   = "v7.1.5";
const String TITLE     = "IW1RMM CW ENCODER";
const int MIN_WPM  = 5;
const int MAX_WPM  = 100;
const int MIN_FREQ = 300;
const int MAX_FREQ = 1200;
unsigned long lastClockUpdate = 0;
#define toneVol1 DAC_CW_SCALE_1
#define toneVol2 DAC_CW_SCALE_2
#define toneVol3 DAC_CW_SCALE_4
#define toneVol4 DAC_CW_SCALE_8

// ============================================================================
// DISPLAY QUEUE messaggi da morseTask lvglTask
// ============================================================================
typedef enum {
  DISP_TX_LED = 0,   // payload: u8 (0=off, 1=on)
  DISP_TX_BAR,       // payload: char (append to blue bar)
  DISP_CLEAR,        // clear all display areas
  DISP_WPM,          // payload: i32 (new wpm value)
  DISP_VOL,          // payload: i32 (new vol level)
  DISP_FREQ,         // payload: i32 (new freq value)
  DISP_IAMBIC_MODE,  // payload: i32 (KeyerMode enum)
  DISP_KEYER_LABEL,  // payload: i32 (0=KEYER/yellow, 1=BUFFER/green)
  DISP_TUNE,         // payload: u8 (0=off, 1=on)
  DISP_BEACON,       // payload: u8 (0=off, 1=on)
  DISP_FARNSWORTH,   // payload: i32 (WPM se >0=ON, 0=OFF)
} DisplayMsgType;

typedef struct {
  DisplayMsgType type;
  union {
    int32_t  i32;
    uint8_t  u8;
    char     ch;
  } payload;
} DisplayMsg;

static QueueHandle_t displayQueue = NULL;

// Helper: post dal morseTask senza bloccare
inline void postDisplay(DisplayMsgType t, int32_t val = 0) {
  DisplayMsg m;
  m.type        = t;
  m.payload.i32 = val;
  xQueueSend(displayQueue, &m, 0);   // non-blocking: se piena, scarta
}
inline void postDisplayChar(char c) {
  // Espandi prosign e caratteri speciali in etichette leggibili <XX>
  const char* prosign = nullptr;
  switch ((unsigned char)c) {
    case '+':  prosign = "<AR>"; break;  // .-.-. AR end of message
    case '=':  prosign = "<BT>"; break;  // -...- BT paragraph/separator
    case '~':  prosign = "<SK>"; break;  // ...-.- SK end of work
    case '^':  prosign = "<SN>"; break;  // ...-. SN understood
    case '&':  prosign = "<AS>"; break;  // .-... AS wait
    case '(':  prosign = "<KN>"; break;  // -.--.  KN over to you only
    default:   break;
  }
  if (prosign) {
    // Manda ogni carattere dell'etichetta sulla queue
    for (const char* p = prosign; *p; p++) {
      DisplayMsg m;
      m.type       = DISP_TX_BAR;
      m.payload.ch = *p;
      xQueueSend(displayQueue, &m, 0);
    }
  } else {
    DisplayMsg m;
    m.type       = DISP_TX_BAR;
    m.payload.ch = c;
    xQueueSend(displayQueue, &m, 0);
  }
}

// ============================================================================
// MUTEX per variabili condivise
// ============================================================================
static SemaphoreHandle_t xMutex = NULL;

#define LOCK()   xSemaphoreTake(xMutex, portMAX_DELAY)
#define UNLOCK() xSemaphoreGive(xMutex)

// ============================================================================
// GLOBAL VARIABLES
// ============================================================================
TFT_eSPI        tft = TFT_eSPI();
SPIClass touchSPI(HSPI);
XPT2046_Touchscreen touchscreen(XPT2046_CS, XPT2046_IRQ);
Preferences     preferences;

int touch_x_min, touch_x_max, touch_y_min, touch_y_max;

static lv_disp_draw_buf_t draw_buf;
static lv_color_t         buf[screenWidth * 10];

// Morse parameters (accesso con LOCK se scritti da UI task)
int    wpm         = 20;
int    audioTone   = 600;
int    volumeLevel = 2;
dac_cosine_atten_t toneVol = toneVol2;
bool   isMuted     = false;

float  dahRatio       = 3.0f;
float  spacing_Weight = 1.0f;
bool   paddleReversed = false;
int    beaconIntervalSec = 60;
int    contestCounter    = 1;
long gmtOffsetHours = 0; // 

float  ditLength  = 60.0f;
float  dahLength  = 180.0f;
float  charSpace  = 180.0f;
float  elemSpace  = 60.0f;
float  wordSpace_ = 420.0f;

// Farnsworth Timing
bool   farnsworthEnabled = false;  // On/Off
int    farnsworthWPM = 12;         // Effective WPM (spacing più lento)
int    tempFarnsworthWPM = 12;  // ← AGGIUNGI QUESTA RIGA (valore temporaneo nel popup)

// SD Card Logging e // VARIABILI GLOBALI HSCW
bool     sdLoggingEnabled = false;   // On/Off
File     logFile;                     // File handle
String   logFileName = "";            // Nome file corrente
unsigned long systemStartTime = 0;   // millis() all'avvio (per uptime)

// HSCW popup slider
int      tempHscwWPM = 60;           // Valore temporaneo slider
lv_obj_t *popupHscwSlider = NULL;    // Slider LVGL
lv_obj_t *popupHscwLabel = NULL;     // Label valore
// OROLOGIO
lv_obj_t * ui_LabelClock = NULL; // Aggiungi questa riga in alto

// Paddle state (solo morseTask scrive/legge)
volatile int  LEFTpaddleState  = HIGH;
volatile int  RIGHTpaddleState = HIGH;
int  ditPaddleFlag  = 0;
int  dahPaddleFlag  = 0;
bool dahOnFlag      = false;
bool ditOnFlag      = false;
bool dahToneFlag    = false;
bool ditToneFlag    = false;
bool manual_ON      = false;
unsigned long paddleStartTime = 0;
unsigned long paddleEndTime   = 0;
unsigned long paddleCountTime = 0;

// Paddle decoder identico al vecchio sketch VK2IDL
// morseNum accumula i bit (dit=1, dah=0) per decodifica
static int           morseNum      = 1;    // accumulatore albero binario
static bool          paddleChar    = false; // carattere pronto per decodifica
static bool          paddleSpace   = false; // flag word space
static unsigned long paddleOutTime = 0;     // fine ultimo elemento
static unsigned long paddleInTime  = 0;     // tempo corrente

// Tabella mySet[] estesa ITU-R M.1677 + prosign
// Accesso: morseNum parte da 1, dit = morseNum<<1, dah = (morseNum<<1)+1
// Prosign visibili: SK=~ (..-.-)  SN=^ (...-.)  KN/paren=( (-.--.)
static const char mySet[] = {
  0,    //   0  unused
  ' ',  //   1  root / word space
  'E',  //   2  .
  'T',  //   3  -
  'I',  //   4  ..
  'A',  //   5  .-
  'N',  //   6  -.
  'M',  //   7  --
  'S',  //   8  ...
  'U',  //   9  ..-
  'R',  //  10  .-.
  'W',  //  11  .--
  'D',  //  12  -..
  'K',  //  13  -.-
  'G',  //  14  --.
  'O',  //  15  ---
  'H',  //  16  ....
  'V',  //  17  ...-
  'F',  //  18  ..-.
  0,    //  19  ..--
  'L',  //  20  .-..
  0,    //  21  .-.- (prefisso AR)
  'P',  //  22  .--.
  'J',  //  23  .---
  'B',  //  24  -...
  'X',  //  25  -..-
  'C',  //  26  -.-.
  'Y',  //  27  -.--
  'Z',  //  28  --..
  'Q',  //  29  --.-
  0,    //  30  ---.
  0,    //  31  ----
  '5',  //  32  .....
  '4',  //  33  ....-
  '^',  //  34  ...-. SN understood
  '3',  //  35  ...--
  0,    //  36
  0,    //  37
  0,    //  38
  '2',  //  39  ..---
  '&',  //  40  .-... AS/wait
  0,    //  41
  '+',  //  42  .-.-. AR  (era erroneamente a 43)
  0,    //  43  .-.-- non assegnato
  0,    //  44
  0,    //  45
  0,    //  46
  '1',  //  47  .----
  '6',  //  48  -....
  '=',  //  49  -...- BT
  '/',  //  50  -..-.  slash
  0,    //  51
  0,    //  52
  0,    //  53
  '(',  //  54  -.--.  KN / open paren
  0,    //  55
  '7',  //  56  --...
  0,    //  57
  0,    //  58
  0,    //  59
  '8',  //  60  ---.
  0,    //  61
  '9',  //  62  ----.
  '0',  //  63  -----
  0,    //  64
  0,    //  65
  0,    //  66
  0,    //  67
  0,    //  68
  '~',  //  69  ...-.- SK end of work
  0,    //  70
  0,    //  71
  0,    //  72
  0,    //  73
  0,    //  74
  0,    //  75
  '?',  //  76  ..--.. question mark
  0,    //  77
  0,    //  78
  0,    //  79
  0,    //  80
  0,    //  81
  0,    //  82
  0,    //  83
  0,    //  84
  '.',  //  85  .-.-.- period
  0,    //  86
  0,    //  87
  0,    //  88
  0,    //  89
  '@',  //  90  .--.-. at sign
  0,    //  91
  0,    //  92
  0,    //  93
  '\'', //  94  .----. apostrophe
  0,    //  95
  0,    //  96
  '-',  //  97  -....- hyphen
  0,    //  98
  0,    //  99
  0,    // 100
  0,    // 101
  0,    // 102
  0,    // 103
  0,    // 104
  0,    // 105
  ';',  // 106  -.-.-. semicolon
  '!',  // 107  -.-.-- exclamation
  0,    // 108
  ')',  // 109  -.--.- close paren
  0,    // 110
  0,    // 111
  0,    // 112
  0,    // 113
  0,    // 114
  ',',  // 115  --..-- comma
  0,    // 116
  0,    // 117
  0,    // 118
  0,    // 119
  ':',  // 120  ---... colon
};
static const int mySetSize = sizeof(mySet);

// Stato morse (condivisi - usa LOCK)
String buffer       = "";
bool   isTuneMode   = false;
bool   isTxActive   = false;
bool   stopRequested = false;

bool     sdBusReady = false;   // bus pronto
bool     sdAvailable  = false; // SD inizializzata correttamente

// Testo caricato
String   sdText       = "";    // testo completo del file
String   sdFileName   = "";    // nome file corrente
int      sdCharIndex  = 0;     // indice prossimo carattere da inviare

// Stato player
enum SdState { SD_IDLE, SD_PLAYING, SD_PAUSED };
volatile SdState sdState = SD_IDLE;

// File list
static const int SD_MAX_FILES = 20;
String   sdFileList[SD_MAX_FILES];
int      sdFileCount  = 0;

// UI refs (tab SD)
lv_obj_t *lblSdFile    = NULL;  // nome file + lunghezza
lv_obj_t *lblSdInfo    = NULL;  // freq + vol
lv_obj_t *lblSdText    = NULL;  // preview testo (riga 1)
lv_obj_t *lblSdRow[5] = {NULL,NULL,NULL,NULL,NULL}; // 5 righe testo SD
lv_obj_t *lblSdWpm     = NULL;  // valore WPM
lv_obj_t *btnSdPlay    = NULL;
lv_obj_t *btnSdPause   = NULL;
lv_obj_t *btnSdStop    = NULL;
lv_obj_t *sdPopup      = NULL;  // popup lista file
bool   beaconActive  = false;
unsigned long beaconInterval  = 60000UL;
unsigned long lastBeaconTime  = 0;

// Keyer mode
enum KeyerMode { IAMBIC_A, IAMBIC_B, MANUAL, AUTO_MODE };
KeyerMode currentMode = IAMBIC_B;
bool isBufferMode = false;

enum QrssMode {
  QRSS_OFF  = 0,
  QRSS_3    = 3,    // 3 secondi per dit
  QRSS_6    = 6,    // 6 secondi per dit
  QRSS_10   = 10,   // 10 secondi per dit
  QRSS_30   = 30    // 30 secondi per dit
};
// QRSS (Slow Speed CW)
QrssMode qrssMode = QRSS_OFF;        // Modalità QRSS corrente
float    qrssDitMs = 1000.0f;        // Durata dit in ms (calcolato da qrssMode)

// BLE (Bluetooth Low Energy)
bool bleEnabled = false;
bool bleClientConnected = false;
volatile bool bleUiUpdatePending = false;
volatile bool bleLogEnabledPending = false;
volatile bool bleLogDisabledPending = false;
BLEServer         *bleServer             = NULL;
BLECharacteristic *bleTxCharacteristic  = NULL;
BLECharacteristic *bleRxCharacteristic  = NULL;
String bleRxBuffer = "";

// Messaggi predefiniti
String cqMessage     = "CQ CQ DE IW1RMM IW1RMM K";
String nameMessage   = "NAME MAURI MAURI K";
String antRigMessage = "RIG IC7300 ANT DIPOLE K";
String qthMessage    = "QTH MILAN MILAN K";
String rstMessage    = "UR 599 599 K";
String testMessage   = "TEST DE IW1RMM K";
String macroMessage  = "";
// K3NG memories A-ZwinkeyModecheckSerialWinkey()
#define NUM_MEM 26
String k3ngMem[NUM_MEM];   // k3ngMem[0]=A ... k3ngMem[25]=Z

// ============================================================================
// WINKEY WK3 PROTOCOL - variabili globali
// ============================================================================
bool     winkeyMode = false;         // true=Winkey, false=K3NG
bool     winkeyHostOpen = false;     // Winkey handshake completato
uint8_t  winkeyVersion = 0x23;       // Version byte WK2 (0x23 = rev 2.3)
uint8_t  winkeyModeReg = 0x00;       // Mode register (Iambic B = 0x00 per spec WK3)
uint8_t  winkeyStatusByte = 0xC0;    // Status byte corrente (0xC0=idle, tag MSB=110)
bool     winkeyTune = false;         // Tune mode attivo via Winkey
unsigned long winkeyLastStatus = 0;  // Timestamp ultimo status inviato
// Winkey PTT / timing parameters
uint8_t wkPttLead        = 0;   // 0x04 p1: PTT lead time (x10ms)
uint8_t wkPttTailTime    = 0;   // 0x04 p2: PTT tail time (x10ms)
uint8_t wkFirstExtension = 0;   // 0x10 First extension (ms)
uint8_t wkKeyComp        = 0;   // 0x11 Key compensation (ms)
uint8_t wkPaddleSP       = 50;  // 0x12 Paddle switchpoint (default 50%)
uint8_t wkPttTail        = 0;   // 0x1A PTT tail buffered
uint8_t wkPttLeadTail    = 0;   // 0x1B PTT lead/tail buffered
// Speed pot (nessun hardware pot fisico)
uint8_t wkSpeedPotMin    = 5;   // 0x05 MinWPM
uint8_t wkSpeedPotRange  = 35;  // 0x05 WPM Range
// X1MODE / X2MODE / PinCfg extension registers
uint8_t wkX1Mode         = 0;   // Admin 0x0F p15 / Admin subcmd 0x0F
uint8_t wkX2Mode         = 0;   // Load Defaults p9
uint8_t wkPinCfg         = 0x05; // 0x09 PinConfig default (PTT+Sidetone enable)

// ============================================================================
// NUOVI FLAG v71
// ============================================================================
bool txEnabled   = true;   // \X — TX key output enable/disable
bool echoEnabled = false;  // \E — Echo paddle chars to Serial/BLE

// Winkey buffer (per gestire messaggi parziali)
#define WINKEY_BUF_SIZE 120
uint8_t  winkeyBuf[WINKEY_BUF_SIZE];
int      winkeyBufLen = 0;

bool contestMode   = false;
bool contestActive = false;

// Display ticker a 3 righe (solo lvglTask/loop)
// Ogni riga larga MAX_COLS caratteri, riempita di spazi inizialmente
// I nuovi caratteri entrano da DESTRA, tutto scorre verso SINISTRA
// Display scroll buffers logica identica al vecchio sketch VK2IDL originale
// L3=barra blu (font grande), L2=nera bassa, L1=nera alta
// drawRightString equivalente: label allineata a destra, testo cresce da sinistra
String stringBuf_L3 = "";   // riga blu (attiva): max buffMainMax chars
String stringBuf_L2 = "";   // nera bassa (overflow L3)
String stringBuf_L1 = "";   // nera alta  (overflow L2)
const int buffMainMax = 32; // max chars riga blu   (font_16, ~9.5px/char su 316px)
const int buffSecMax  = 42; // max chars righe nere (font_12)

// Timer
hw_timer_t       *morseTimer     = NULL;
volatile uint32_t morseTimerTick = 0;

// Task handles
TaskHandle_t morseTaskHandle  = NULL;
// lvglTaskHandle rimosso: LVGL gira nel loop()
TaskHandle_t serialTaskHandle = NULL;

// ============================================================================
// LVGL OBJECTS
// ============================================================================
lv_obj_t *tabview, *tabMorse1, *tabMorse2, *tabSD, *tabSettings, *tabSpare;
lv_obj_t *labelTxLed;
lv_obj_t *labelLog1, *labelLog2, *labelTx;
lv_obj_t *btnCQ, *btnName, *btnAntRig, *btnClear;
lv_obj_t *btnProtocol = NULL;  // K3NG/Winkey toggle (tab Settings)
lv_obj_t *btnFarnsworth = NULL;  // Farnsworth toggle (tab Settings)
lv_obj_t *btnSdLog = NULL;  // SD Logging toggle (tab Settings)
lv_obj_t *btnQrss = NULL;  // QRSS toggle (tab Settings)
lv_obj_t *btnBle = NULL;  // BLE toggle (tab Settings)
lv_obj_t *btnQth, *btnRst, *btnTest, *btnKeyerMode;
lv_obj_t *btnRatio, *btnWeight, *btnTune, *btnMacro;
lv_obj_t *btnPadRev, *btnBeacon, *btnContest, *btnStop;
lv_obj_t *btnWpmUp, *btnWpmDown, *btnVolUp, *btnVolDown, *btnFreqUp, *btnFreqDown;
lv_obj_t *btnIambicMode;
lv_obj_t *ledTxCircle;
lv_obj_t *ledTxCircle1, *ledTxCircle2;
lv_obj_t *btnIambicMode1, *btnIambicMode2;
lv_obj_t *labelLog1_t1, *labelLog2_t1, *labelTx_t1;
lv_obj_t *labelLog1_t2, *labelLog2_t2, *labelTx_t2;
lv_obj_t *labelWpm1, *labelVol1, *labelFreq1;
lv_obj_t *labelWpm2, *labelVol2, *labelFreq2;

// Popup
lv_obj_t *popupBox        = NULL;
// Variabili per il popup di Farnsworth
lv_obj_t *popupValueLabel = NULL;      // usata da altri popup (ratio, weight, ecc)
lv_obj_t *popupFarnsworthLabel1 = NULL; // label "Effective: xx WPM"
lv_obj_t *popupFarnsworthLabel2 = NULL; // label "Chars: xx WPM"
// Fine Variabili per il popup di Farnsworth

// Editor messaggi
lv_obj_t *msgEditorBox    = NULL;
lv_obj_t *msgEditorKb     = NULL;   // keyboard su lv_layer_top()
lv_obj_t *msgEditorTA     = NULL;   // textarea
int       msgEditIndex    = -1;     // 0=CQ,1=NAME,2=ANTRIG,3=QTH,4=RST,5=TEST
void showMsgEditor(int idx);
void onMsgEditorSave(lv_event_t *e);
void onMsgEditorCancel(lv_event_t *e);
float tempRatio   = 3.0f;
float tempWeight  = 1.0f;
bool  tempPadRev  = false;
int   tempBeacon  = 60;
int   tempContest = 1;

// Volume display helpers
int volumeUiLevel(int v) { return (v == 0) ? 0 : 5 - v; }

// ============================================================================
// FUNCTION PROTOTYPES
// ============================================================================
void setupPins();
void setupTouch();
void setupLVGL();
void setupTasks();
void setupTimer();
void loadPreferences();
void savePreferences();
void calculateMorseTiming();

void my_disp_flush(lv_disp_drv_t*, const lv_area_t*, lv_color_t*);
void my_touchpad_read(lv_indev_drv_t*, lv_indev_data_t*);

void createUI();
void createTabMorse1();
void createTabMorse2();
void createTabSD();
void sdScanFiles(String targetFile = "");
void sdLoadFile(String filename);
void sdOpenFilePopup();
void sdCloseFilePopup();
void sdUpdateFileLabel();
void sdUpdateInfoLabel();
void sdUpdateWpmLabel();
void sdUpdateButtons();
void sdPlayerTask();    // chiamata da loop() - invia char al buffer Morse
void createTabSettings();
void createTabSpare();
void createLogAreas(lv_obj_t*);
void createCommonControls(lv_obj_t*, lv_obj_t**, lv_obj_t**, lv_obj_t**, lv_obj_t**, lv_obj_t**);
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
void loop() {

  // ===============================
// BLE deferred operations (SAFE)
// ===============================
if (bleUiUpdatePending) {
  bleUiUpdatePending = false;
    updateBleButton();
}

if (bleLogEnabledPending) {
  bleLogEnabledPending = false;
  sdLogWrite("BLE enabled");
}

if (bleLogDisabledPending) {
  bleLogDisabledPending = false;
  sdLogWrite("BLE disabled");
}

  processDisplayQueue();   // consuma messaggi da morseTask
  lv_timer_handler();      // LVGL ridisegna e processa touch

  // SD Player: inietta prossimo carattere nel buffer morse quando in play
  sdPlayerTask();

  // Aggiorna label freq/vol/wpm nel tab SD ogni 2 secondi
  static uint32_t lastSdInfoMs = 0;
  if (millis() - lastSdInfoMs > 2000) {
    sdUpdateInfoLabel();
    sdUpdateWpmLabel();
    lastSdInfoMs = millis(); 
  }

 if (millis() - lastClockUpdate >= 1000) {
    lastClockUpdate = millis();
    updateClockLVGL();
  }
  delay(5);                // 5ms valore raccomandato LVGL
}

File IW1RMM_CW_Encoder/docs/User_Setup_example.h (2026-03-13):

//                            USER DEFINED SETTINGS
//				For Arduino Library
//   Set driver type, fonts to be loaded, pins used and SPI control method etc
//
//   See the User_Setup_Select.h file if you wish to be able to define multiple
//   setups and then easily select which setup file is used by the compiler.
//
//   If this file is edited correctly then all the library example sketches should
//   run without the need to make any more changes for a particular hardware setup!
//   Note that some sketches are designed for a particular TFT pixel width/height

// User defined information reported by "Read_User_Setup" test & diagnostics example
#define USER_SETUP_INFO "User_Setup"

// Define to disable all #warnings in library (can be put in User_Setup_Select.h)
//#define DISABLE_ALL_LIBRARY_WARNINGS

// ##################################################################################
//
// Section 1. Call up the right driver file and any options for it
//
// ##################################################################################

// Define STM32 to invoke optimised processor support (only for STM32)
//#define STM32

// Defining the STM32 board allows the library to optimise the performance
// for UNO compatible "MCUfriend" style shields
//#define NUCLEO_64_TFT
//#define NUCLEO_144_TFT

// STM32 8 bit parallel only:
// If STN32 Port A or B pins 0-7 are used for 8 bit parallel data bus bits 0-7
// then this will improve rendering performance by a factor of ~8x
//#define STM_PORTA_DATA_BUS
//#define STM_PORTB_DATA_BUS

// Tell the library to use parallel mode (otherwise SPI is assumed)
//#define TFT_PARALLEL_8_BIT
//#defined TFT_PARALLEL_16_BIT // **** 16 bit parallel ONLY for RP2040 processor ****

// Display type -  only define if RPi display
//#define RPI_DISPLAY_TYPE // 20MHz maximum SPI

// Only define one driver, the other ones must be commented out
//#define ILI9341_DRIVER       // Generic driver for common displays
#define ILI9341_2_DRIVER     // Alternative ILI9341 driver, see https://github.com/Bodmer/TFT_eSPI/issues/1172
//#define ST7735_DRIVER      // Define additional parameters below for this display
//#define ILI9163_DRIVER     // Define additional parameters below for this display
//#define S6D02A1_DRIVER
//#define RPI_ILI9486_DRIVER // 20MHz maximum SPI
//#define HX8357D_DRIVER
//#define ILI9481_DRIVER
//#define ILI9486_DRIVER
//#define ILI9488_DRIVER     // WARNING: Do not connect ILI9488 display SDO to MISO if other devices share the SPI bus (TFT SDO does NOT tristate when CS is high)
//#define ST7789_DRIVER      // Full configuration option, define additional parameters below for this display
//#define ST7789_2_DRIVER    // Minimal configuration option, define additional parameters below for this display
//#define R61581_DRIVER
//#define RM68140_DRIVER
//#define ST7796_DRIVER
//#define SSD1351_DRIVER
//#define SSD1963_480_DRIVER
//#define SSD1963_800_DRIVER
//#define SSD1963_800ALT_DRIVER
//#define ILI9225_DRIVER
//#define GC9A01_DRIVER

// Some displays support SPI reads via the MISO pin, other displays have a single
// bi-directional SDA pin and the library will try to read this via the MOSI line.
// To use the SDA line for reading data from the TFT uncomment the following line:

// #define TFT_SDA_READ      // This option is for ESP32 ONLY, tested with ST7789 and GC9A01 display only

// For ST7735, ST7789 and ILI9341 ONLY, define the colour order IF the blue and red are swapped on your display
// Try ONE option at a time to find the correct colour order for your display

  //#define TFT_RGB_ORDER TFT_RGB  // Colour order Red-Green-Blue
   #define TFT_RGB_ORDER TFT_BGR  // Colour order Blue-Green-Red

// For M5Stack ESP32 module with integrated ILI9341 display ONLY, remove // in line below

// #define M5STACK

// For ST7789, ST7735, ILI9163 and GC9A01 ONLY, define the pixel width and height in portrait orientation
// #define TFT_WIDTH  80
// #define TFT_WIDTH  128
// #define TFT_WIDTH  172 // ST7789 172 x 320
#define TFT_WIDTH  240 // ST7789 240 x 240 and 240 x 320
// #define TFT_HEIGHT 160
// #define TFT_HEIGHT 128
// #define TFT_HEIGHT 240 // ST7789 240 x 240
#define TFT_HEIGHT 320 // ST7789 240 x 320
// #define TFT_HEIGHT 240 // GC9A01 240 x 240

// For ST7735 ONLY, define the type of display, originally this was based on the
// colour of the tab on the screen protector film but this is not always true, so try
// out the different options below if the screen does not display graphics correctly,
// e.g. colours wrong, mirror images, or stray pixels at the edges.
// Comment out ALL BUT ONE of these options for a ST7735 display driver, save this
// this User_Setup file, then rebuild and upload the sketch to the board again:

// #define ST7735_INITB
// #define ST7735_GREENTAB
// #define ST7735_GREENTAB2
// #define ST7735_GREENTAB3
// #define ST7735_GREENTAB128    // For 128 x 128 display
// #define ST7735_GREENTAB160x80 // For 160 x 80 display (BGR, inverted, 26 offset)
// #define ST7735_ROBOTLCD       // For some RobotLCD arduino shields (128x160, BGR, https://docs.arduino.cc/retired/getting-started-guides/TFT)
// #define ST7735_REDTAB
// #define ST7735_BLACKTAB
// #define ST7735_REDTAB160x80   // For 160 x 80 display with 24 pixel offset

// If colours are inverted (white shows as black) then uncomment one of the next
// 2 lines try both options, one of the options should correct the inversion.

 #define TFT_INVERSION_ON
// #define TFT_INVERSION_OFF


// ##################################################################################
//
// Section 2. Define the pins that are used to interface with the display here
//
// ##################################################################################

// If a backlight control signal is available then define the TFT_BL pin in Section 2
// below. The backlight will be turned ON when tft.begin() is called, but the library
// needs to know if the LEDs are ON with the pin HIGH or LOW. If the LEDs are to be
// driven with a PWM signal or turned OFF/ON then this must be handled by the user
// sketch. e.g. with digitalWrite(TFT_BL, LOW);

#define TFT_BL   21            // LED back-light control pin
#define TFT_BACKLIGHT_ON HIGH  // Level to turn ON back-light (HIGH or LOW)
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

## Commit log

2026-03-13 Initial release: IW1RMM CW Encoder v7.1.4
2026-03-16 Add 3D printable case STL files
    [Case-Front_Panel.stl, Case-Rear_Panel.stl, Speaker-Cap.stl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]

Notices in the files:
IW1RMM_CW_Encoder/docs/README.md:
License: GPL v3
